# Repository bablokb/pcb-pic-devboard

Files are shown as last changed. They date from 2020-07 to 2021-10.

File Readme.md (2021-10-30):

Development board for PIC12/PIC16 microcontrollers
==================================================

This repository contains the design-files (Kicad) for three PIC12/PIC16
development boards.

PIC-Dev-Board
-------------

This is a full sized dev-board, see directory `pic-dev-board.kicad`:

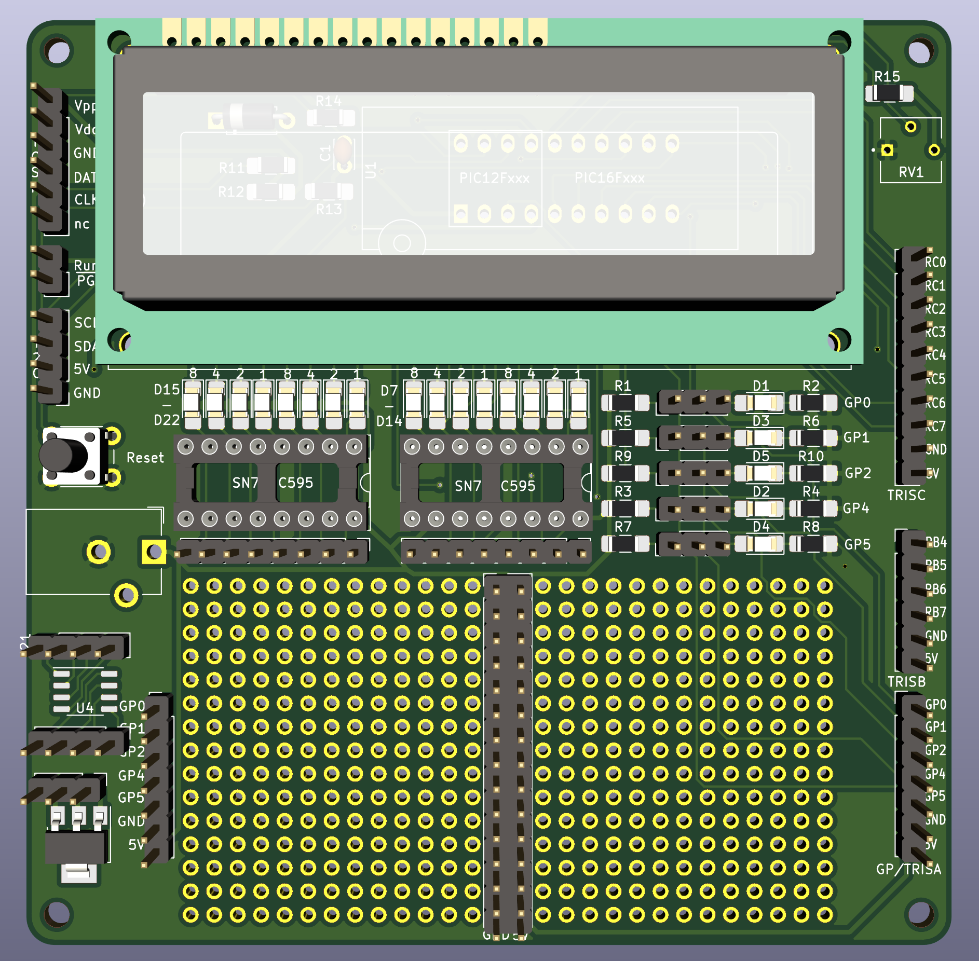
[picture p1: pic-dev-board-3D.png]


It supports:

  - a PIC12 or a 20-pin PIC16
  - configurable pullups or LEDs on GP0-GP5
  - two shift-registers with LEDs to output 8-16 bits using two GPs
    (see [project pic-sn74hc595](https://github.com/bablokb/pic-sn74hc595))
  - a LCD1602 attached to the first shift-register
    (see [project pic-hd44780_lcd](https://github.com/bablokb/pic-hd44780_lcd))
  - ICSP programming
  - all pins broken out to connectors (TRISB/TRISC only available for PIC16)
  - a large prototyping-area

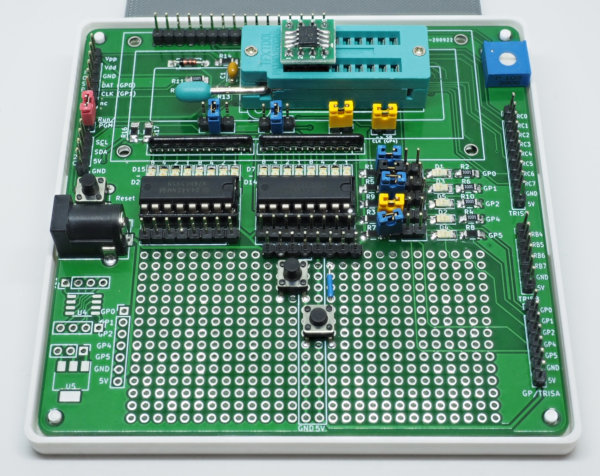
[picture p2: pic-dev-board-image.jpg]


PIC12-Dev-PCB
-------------

This is a small dev-board for PIC12 MCUs designed for plugging into a
breadboard, see directory `pic12-dev-pcb`:

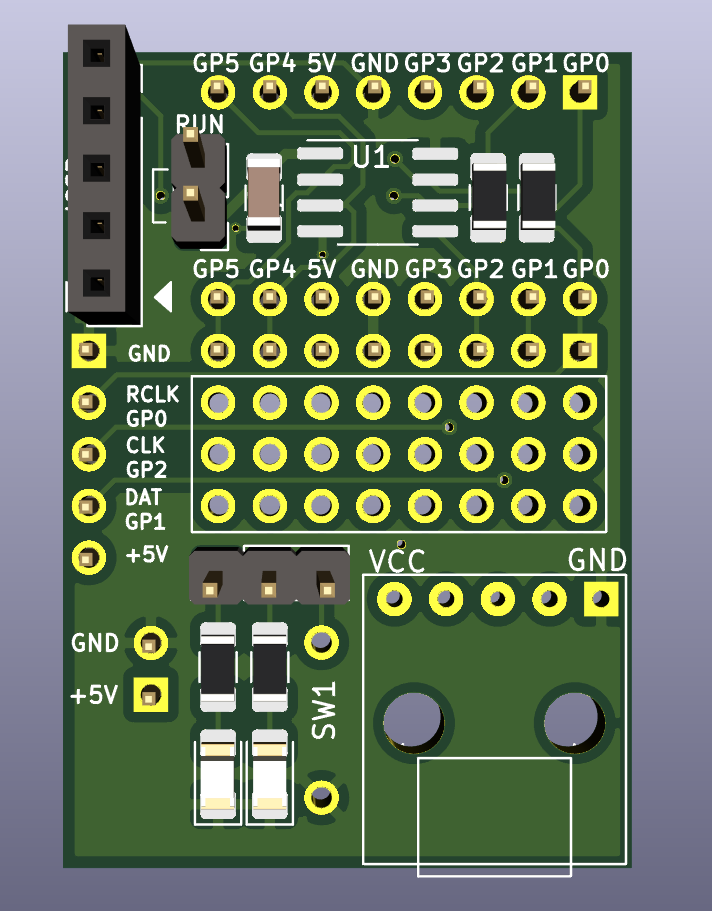
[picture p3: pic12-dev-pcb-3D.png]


It supports:

  - PIC12 in SO-8 package
  - ICSP programming
  - connector for an external SN74HC595-pcb
    (see [project pic-sn74hc595](https://github.com/bablokb/pic-sn74hc595)
  - also usable as I2C-connector
  - power-supply using a small micro-USB-connector breakout
  - connector for power-out (should align with the power-rails of the breadboard)
  - a small prototyping area
  - a small switch (optional)
  - two LEDs (optional)

Minimal Stripboard Version
--------------------------

In the directory `pic12-dev-stripboard.kicad` you find the schema and layout for
a minimal stripboard version:

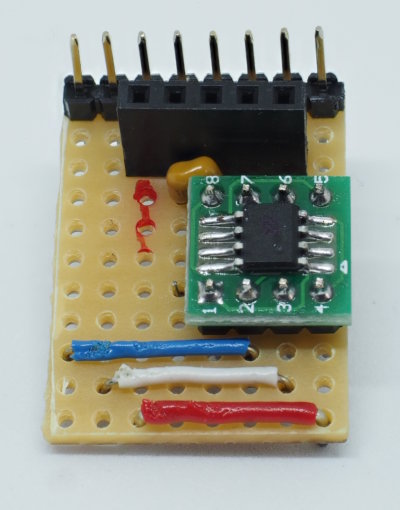
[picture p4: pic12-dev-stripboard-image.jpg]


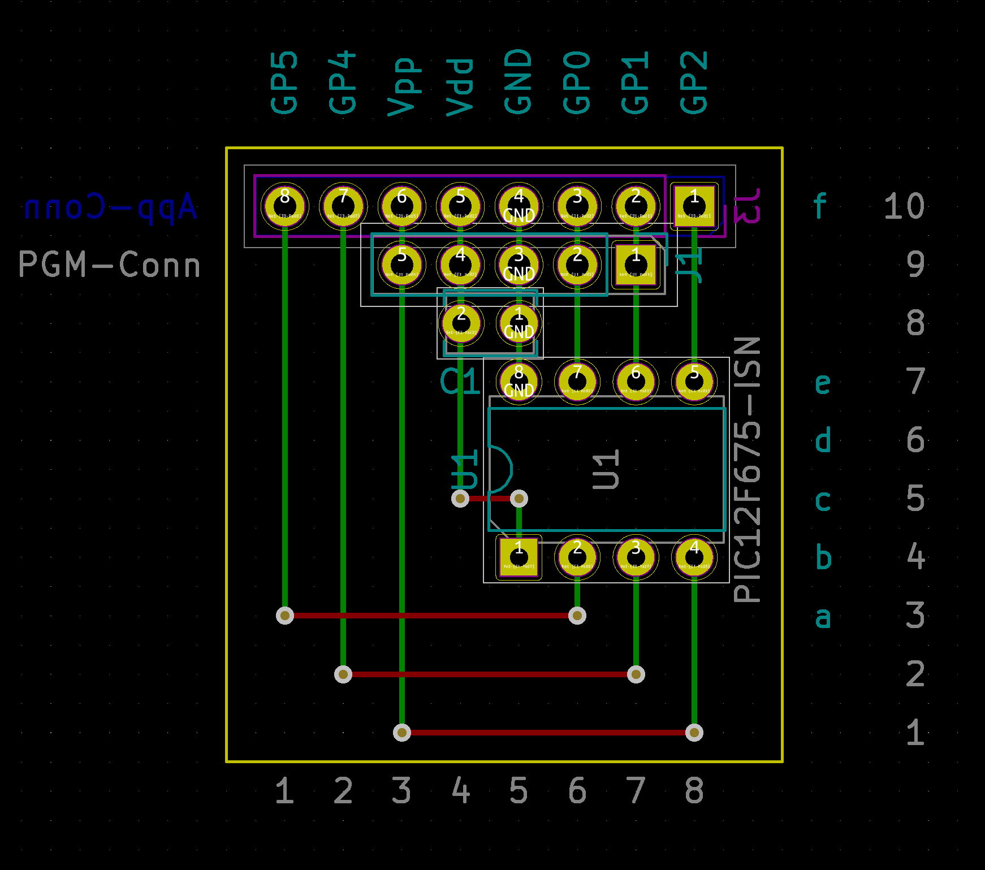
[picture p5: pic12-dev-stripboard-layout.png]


This is a simple solution for plugging a PIC12 into a breadboard.

This version is not meant for ICSP (in-circuit serial
programming), since it does not have any components to guard the rest of the
circuit during programming.

License
-------

Shield: [![CC BY-SA 4.0][cc-by-sa-shield]][cc-by-sa]

This work is licensed under a
[Creative Commons Attribution-ShareAlike 4.0 International
License][cc-by-sa].

[][cc-by-sa]

[cc-by-sa]: http://creativecommons.org/licenses/by-sa/4.0/
[cc-by-sa-image]: https://licensebuttons.net/l/by-sa/4.0/88x31.png
[cc-by-sa-shield]:
https://img.shields.io/badge/License-CC%20BY--SA%204.0-lightgrey.svg

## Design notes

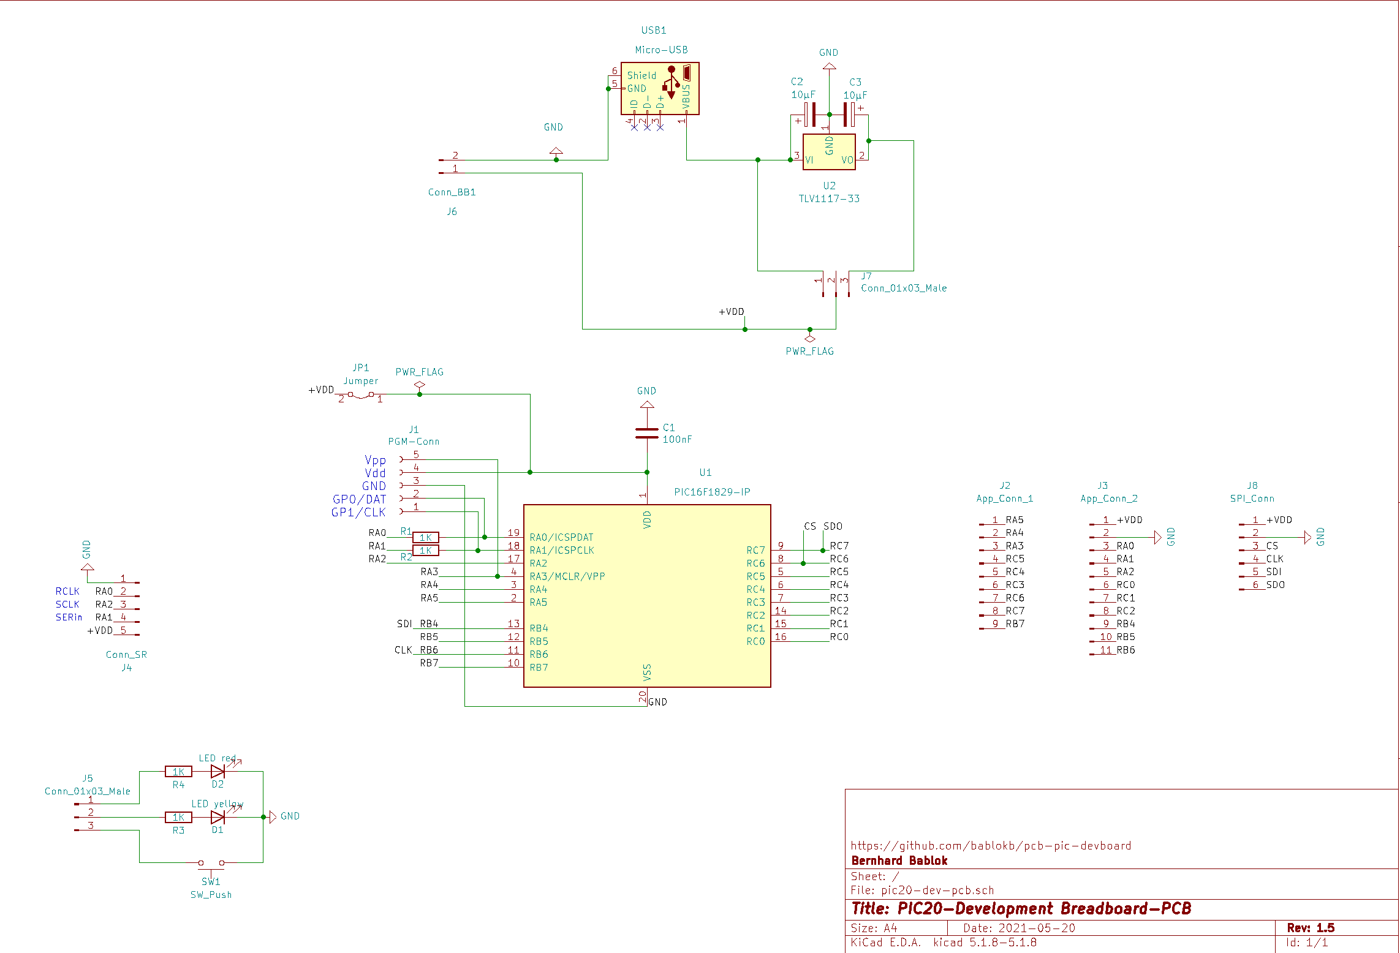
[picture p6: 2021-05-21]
pic20-dev-pcb-schematic.png

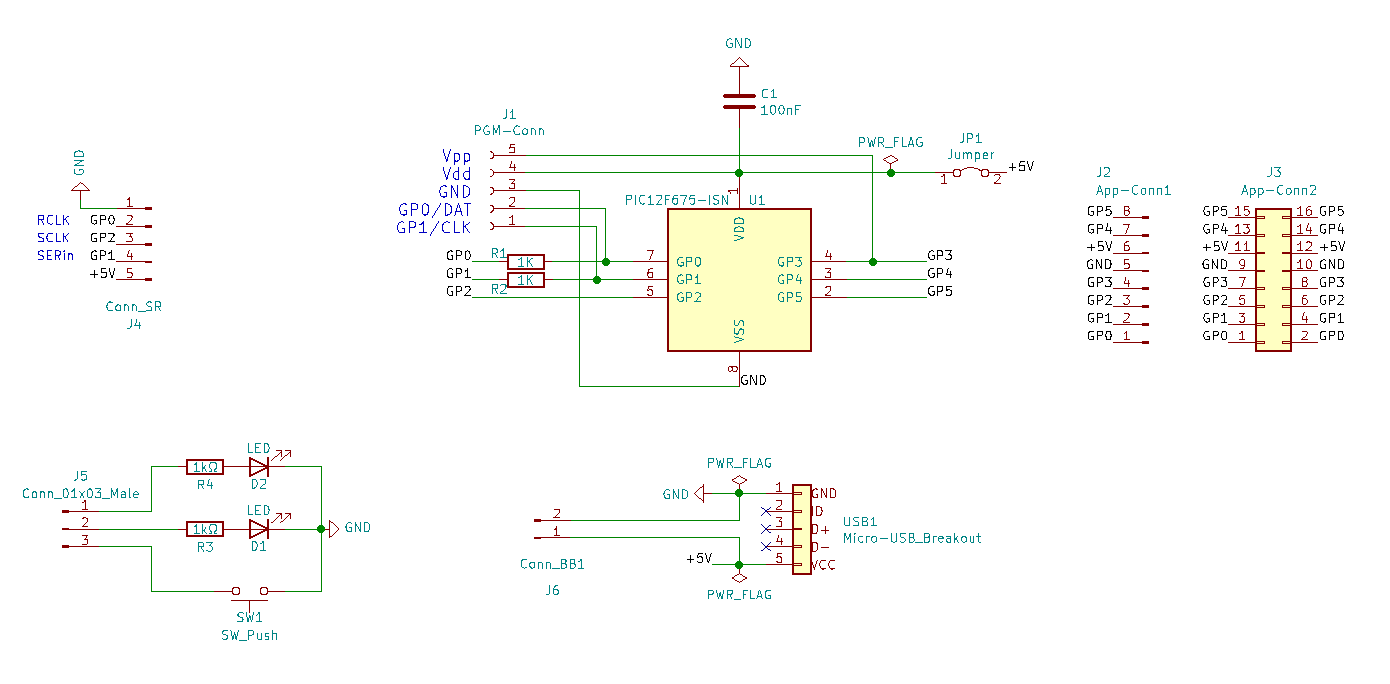
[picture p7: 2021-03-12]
pic12-dev-pcb-schematic.png

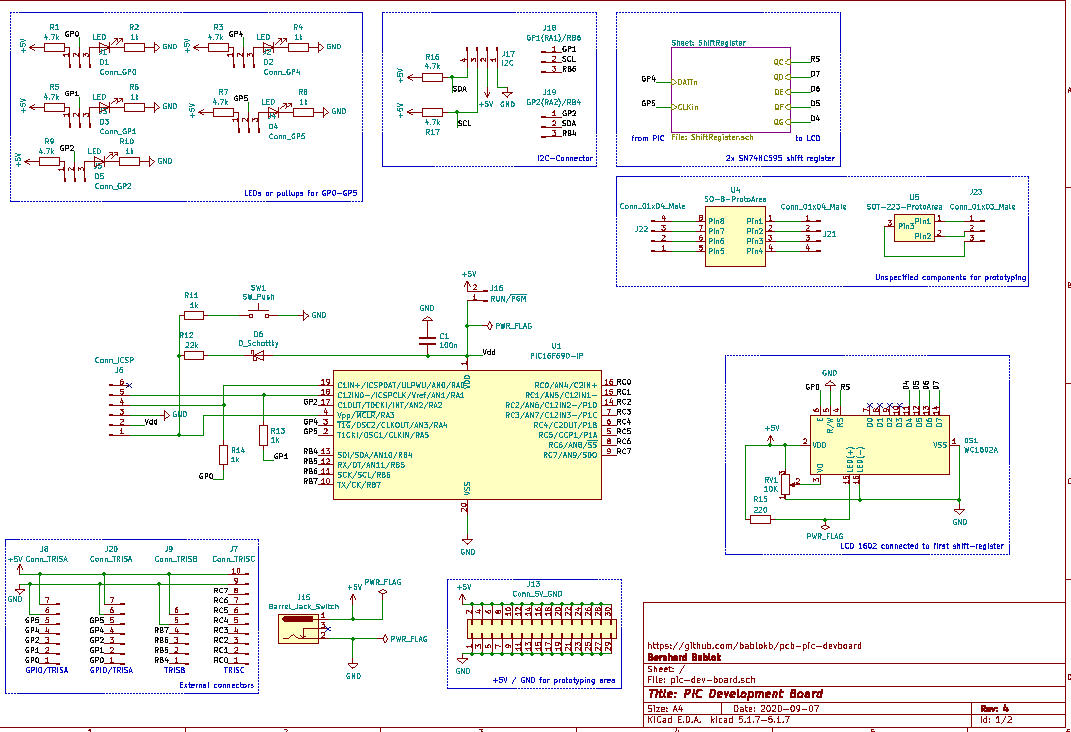
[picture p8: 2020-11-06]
pic-dev-board-schematic.png

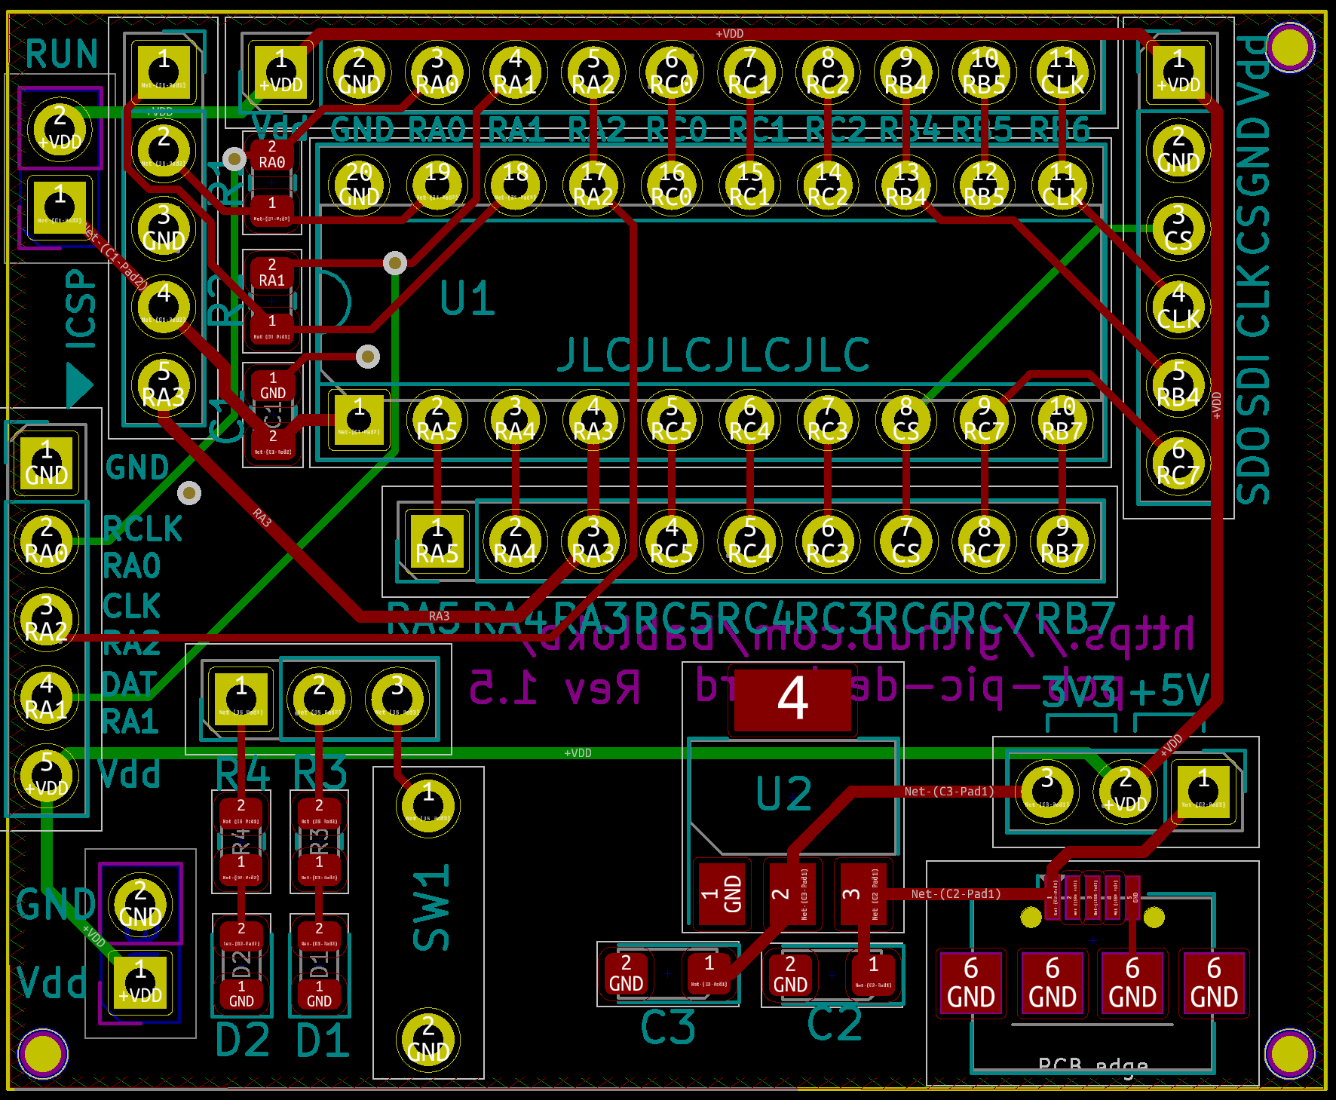
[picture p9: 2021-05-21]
pic20-dev-pcb-layout.png

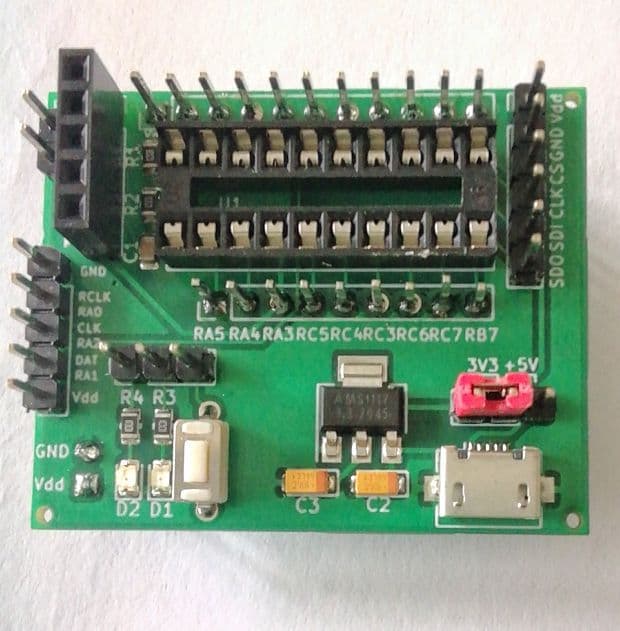
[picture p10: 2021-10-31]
pic20-dev-pcb.jpg

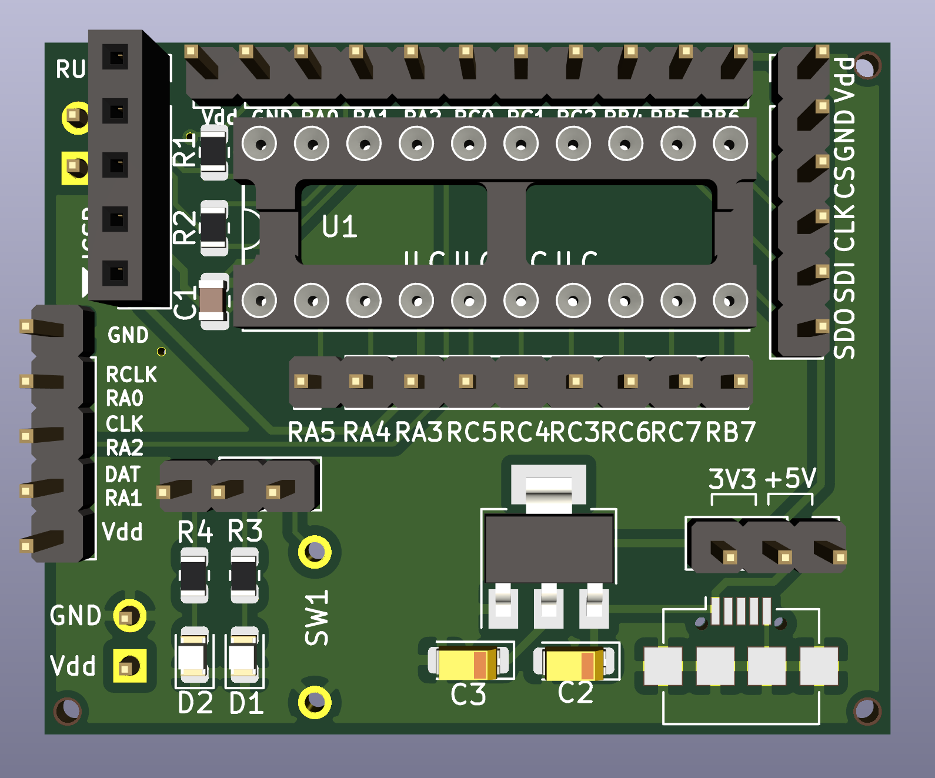
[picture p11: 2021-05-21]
pic20-dev-pcb-3D.png

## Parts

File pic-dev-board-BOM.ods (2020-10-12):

Ref | Qnty | Value | Note
C1 | 1 | 100n, THT 2,5mm | for PIC
D1-D5, D7-D14, D15-D22 | 21 | LED 1206 | for GP0-GP5 and shift-registers
D6 | 1 | BAT85 | PIC programming interface
DS1 | 1 | WC1602A | display, 1x16 female (optional)
J1-J5 | 5 | 1x03 | pullup/led for GP0-GP5 (shunts)
J6 | 1 | 1x06 | ICSP
J7 | 1 | 1x10 | TRISC
J8, J20 | 2 | 1x07 | GP/TRISA
J9 | 1 | 1x06 | TRISB
J10 | 1 | 1x02 | DATin for shift-register (shunt)
J11 | 1 | 1x08 | shift-register out (optional)
J12 | 1 | 1x08 | shift-register out (optional)
(J13) | 1 | 2x15 | GND/5V on prototyping-area (optional)
J14 | 1 | 1x02 | CLKin for shift-register (shunt)
J15 | 1 | Barrel-Jack | Power
J16 | 1 | 1x02 | RUN/PGM (shunt)
J17 | 1 | 1x04 | I2C
J18 | 1 | 1x03 | SCL select GP1/RB6 (shunt)
J19 | 1 | 1x03 | SDA select GP2/RB4 (shunt)
(J21, J22) | 2 | 1x04 | SO-8 breakout (optional)
(J23) | 1 | 1x03 | SOT-223 breakout (optional)
R1, R3, R5, R7, R9 | 5 | SMD 1206 4.7k | pullups for GP0-GP5
R16, R17 | 2 | SMD 1206 4.7k | pullups for I2C
R2, R4, R6, R8, R10 | 5 | SMD 1206 1k | for LEDs on GP0-GP5
R11, R13, R14 | 3 | SMD 1206 1k | PIC programming interface
R12 | 1 | SMD 1206 22k | PIC programming interface
R15 | 1 | SMD 1206 220 | for display (optional)
RN1, RN2 | 2 | R-Net 680 | for shift-register LEDs
RV1 | 1 | TRIM 3362P 10K | for display (optional)
SW1 | 1 | SW_Push | reset
U1 | 1 | test-socket | or normal socket together with display
U2, U3 | 2 | 74HC595 | shift-registers (or 2x8 sockets)
(U4) | 1 | SO-8 | optional
(U5) | 1 | SOT-223 | optional

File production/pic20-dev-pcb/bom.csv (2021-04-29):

Comment | Designator | Footprint | LCSC
100nF | C1 | Capacitor_SMD:C_0805_2012Metric | C49678
10µF | C2,C3 | Capacitor_Tantalum_SMD:CP_EIA-3216-18_Kemet-A | C7171
LED yellow | D1 | LED_SMD:LED_0805_2012Metric | C2296
LED red | D2 | LED_SMD:LED_0805_2012Metric | C84256
PGM-Conn | J1 | Connector_PinSocket_2.54mm:PinSocket_1x05_P2.54mm_Vertical
App_Conn_1 | J2 | Connector_PinHeader_2.54mm:PinHeader_1x09_P2.54mm_Vertical
App_Conn_2 | J3 | Connector_PinHeader_2.54mm:PinHeader_1x11_P2.54mm_Vertical
Conn_SR | J4 | Connector_PinHeader_2.54mm:PinHeader_1x05_P2.54mm_Vertical
Conn_01x03_Male | J5,J7 | Connector_PinHeader_2.54mm:PinHeader_1x03_P2.54mm_Vertical
Conn_BB1 | J6 | Connector_PinHeader_2.54mm:PinHeader_1x02_P2.54mm_Vertical
SPI_Conn | J8 | Connector_PinHeader_2.54mm:PinHeader_1x06_P2.54mm_Vertical
Jumper | JP1 | Connector_PinHeader_2.54mm:PinHeader_1x02_P2.54mm_Vertical
1K | R1,R2,R3,R4 | Resistor_SMD:R_0805_2012Metric | C17513
SW_Push | SW1 | user:SW_PUSH_SLIM_1x4
PIC16F1829-IP | U1 | Package_DIP:DIP-20_W7.62mm_Socket
AMS1117-33 | U2 | Package_TO_SOT_SMD:SOT-223 | C6186
Micro-USB | USB1 | user:USB_Micro-B_JLCPCB_40942 | C40942

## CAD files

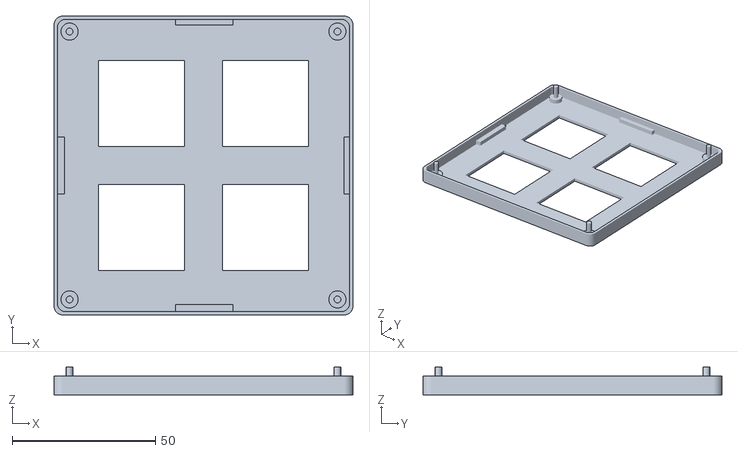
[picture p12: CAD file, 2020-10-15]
pic-dev-board-base.stl
104.3 x 104.3 x 9.60

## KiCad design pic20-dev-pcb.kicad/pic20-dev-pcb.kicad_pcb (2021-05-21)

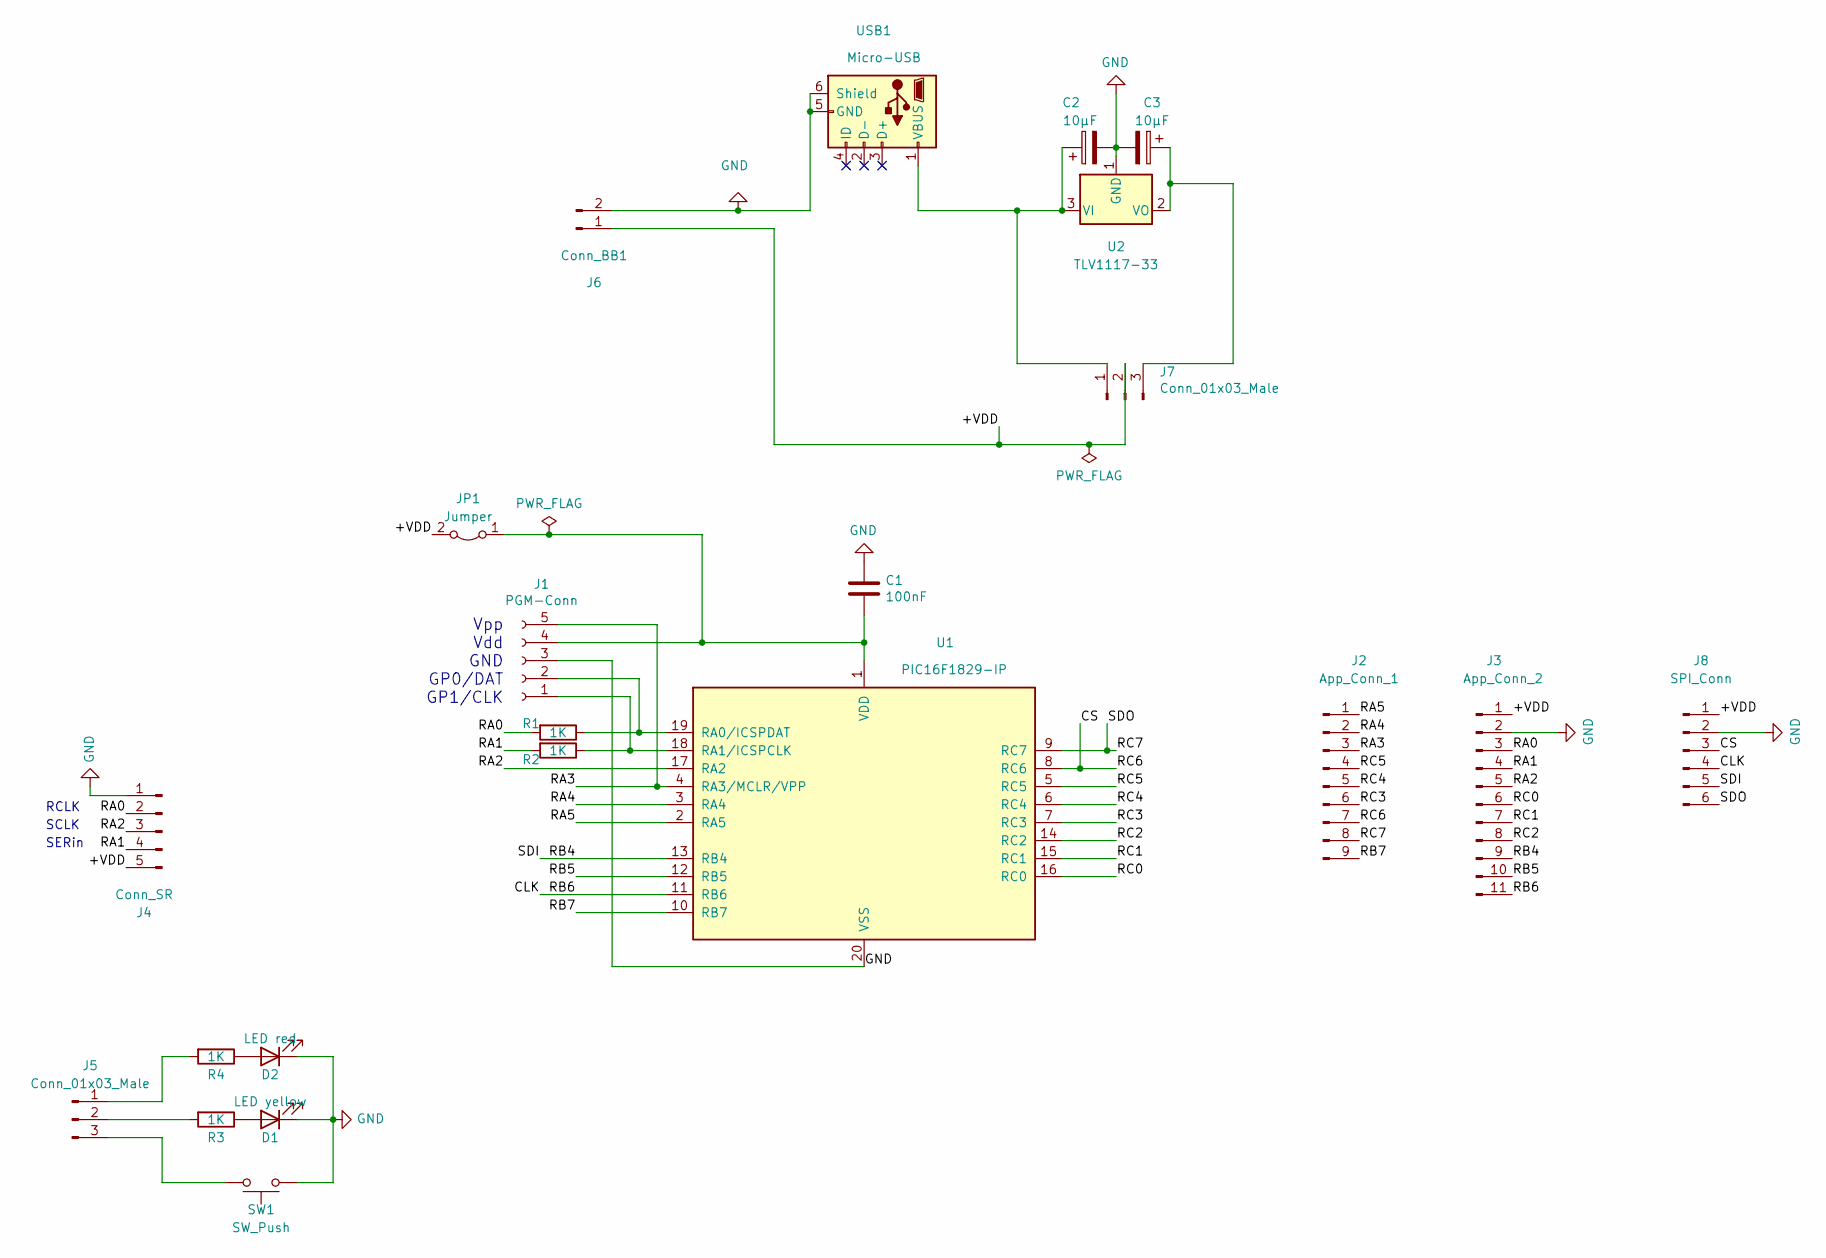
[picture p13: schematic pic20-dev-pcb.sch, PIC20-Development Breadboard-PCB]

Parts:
C1: 100nF; C_0805_2012Metric; LCSC C49678
C2, C3: 10µF; CP_EIA-3216-18_Kemet-A; LCSC C7171
D1: LED yellow; LED_0805_2012Metric; LCSC C2296
D2: LED red; LED_0805_2012Metric; LCSC C84256
J1: PGM-Conn; PinSocket_1x05_P2.54mm_Vertical
J2: App_Conn_1; PinHeader_1x09_P2.54mm_Vertical
J3: App_Conn_2; PinHeader_1x11_P2.54mm_Vertical
J4: Conn_SR; PinHeader_1x05_P2.54mm_Vertical
J5, J7: Conn_01x03_Male; PinHeader_1x03_P2.54mm_Vertical
J6: Conn_BB1; PinHeader_1x02_P2.54mm_Vertical
J8: SPI_Conn; PinHeader_1x06_P2.54mm_Vertical
JP1: Jumper; PinHeader_1x02_P2.54mm_Vertical
R1, R2, R3, R4: 1K; R_0805_2012Metric; LCSC C17513
SW1: SW_Push; SW_PUSH_SLIM_1x4
U1: PIC16F1829-IP; DIP-20_W7.62mm_Socket
U2: TLV1117-33; SOT-223; LCSC C6186
USB1: Micro-USB; USB_Micro-B_JLCPCB_40942; LCSC C40942

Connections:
/+VDD: J3.1, J4.5, J6.1, J7.2, J8.1, JP1.2 (B)
/CLK: J3.11, J8.4, U1.11 (RB6)
/CS: J2.7, J8.3, U1.8 (RC6)
/RA0: J3.3, J4.2, R1.2
/RA1: J3.4, J4.4, R2.2
/RA2: J3.5, J4.3, U1.17 (RA2)
/RA3: J1.5, J2.3, U1.4 (RA3/MCLR/VPP)
/RA4: J2.2, U1.3 (RA4)
/RA5: J2.1, U1.2 (RA5)
/RB4: J3.9, J8.5, U1.13 (RB4)
/RB5: J3.10, U1.12 (RB5)
/RB7: J2.9, U1.10 (RB7)
/RC0: J3.6, U1.16 (RC0)
/RC1: J3.7, U1.15 (RC1)
/RC2: J3.8, U1.14 (RC2)
/RC3: J2.6, U1.7 (RC3)
/RC4: J2.5, U1.6 (RC4)
/RC5: J2.4, U1.5 (RC5)
/RC7: J2.8, J8.6, U1.9 (RC7)
GND: C1.1, C2.2, C3.2, D1.1 (K), D2.1 (K), J1.3, J3.2, J4.1, J6.2, J8.2, SW1.2, U1.20 (VSS), U2.1 (GND), USB1.5 (GND), USB1.6 (Shield)
unnamed: C1.2, J1.4, JP1.1 (A), U1.1 (VDD)
unnamed: C2.1, J7.1, U2.3 (VI), USB1.1 (VBUS)
unnamed: C3.1, J7.3, U2.2 (VO)
unnamed: D1.2 (A), R3.1
unnamed: D2.2 (A), R4.1
unnamed: J1.1, R2.1, U1.18 (RA1/ICSPCLK)
unnamed: J1.2, R1.1, U1.19 (RA0/ICSPDAT)
unnamed: J5.1, R4.2
unnamed: J5.2, R3.2
unnamed: J5.3, SW1.1

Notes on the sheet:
Vpp Vdd GND GP0/DAT GP1/CLK
SERin
RCLK
SCLK

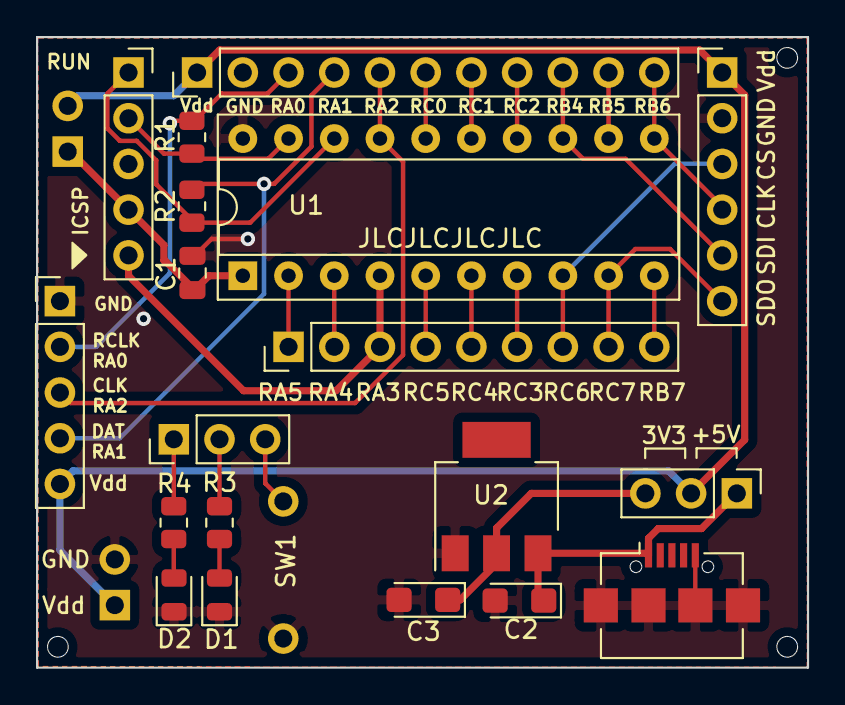
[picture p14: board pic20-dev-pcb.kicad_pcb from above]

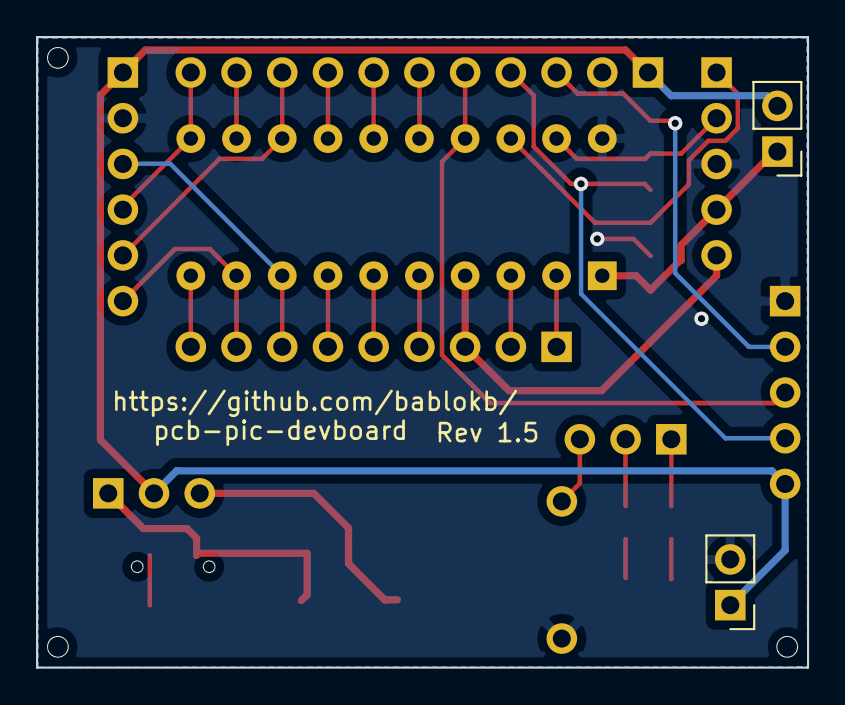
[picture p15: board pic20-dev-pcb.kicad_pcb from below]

Board: 2 copper layers, 42.8 x 35.0 mm, 22 parts (2 on the bottom side), 30 nets.

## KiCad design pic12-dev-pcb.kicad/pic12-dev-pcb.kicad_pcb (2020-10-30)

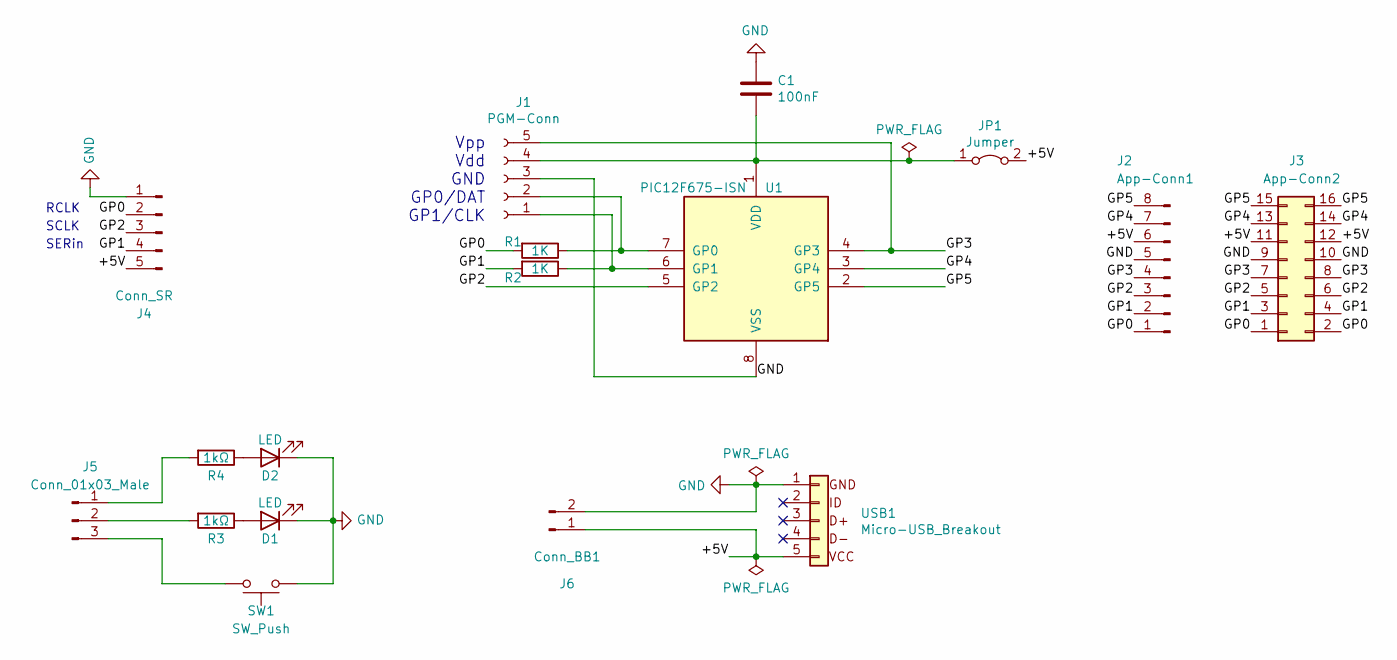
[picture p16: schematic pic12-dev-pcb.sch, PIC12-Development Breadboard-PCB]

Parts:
C1: 100nF; C_1206_3216Metric_Pad1.42x1.75mm_HandSolder
D1, D2: LED; LED_1206_3216Metric_Pad1.42x1.75mm_HandSolder
J1: PGM-Conn; PinSocket_1x05_P2.54mm_Vertical
J2: App-Conn1; PinHeader_1x08_P2.54mm_Vertical
J3: App-Conn2; PinHeader_2x08_P2.54mm_Vertical
J4: Conn_SR; PinHeader_1x05_P2.54mm_Vertical
J5: Conn_01x03_Male; PinHeader_1x03_P2.54mm_Vertical
J6: Conn_BB1; PinHeader_1x02_P2.54mm_Vertical
JP1: Jumper; PinHeader_1x02_P2.54mm_Vertical
R1, R2: 1K; R_1206_3216Metric_Pad1.42x1.75mm_HandSolder
R3, R4: 1kΩ; R_1206_3216Metric_Pad1.30x1.75mm_HandSolder
SW1: SW_Push; SW_PUSH_SLIM_1x4
U1: PIC12F675-ISN; SO-8_3.9x4.9mm_P1.27mm_HandSolder
USB1: Micro-USB_Breakout

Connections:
/+5V: J2.6, J3.11, J3.12, J4.5, J6.1, JP1.2 (B), USB1.5
/GP0: J2.1, J3.1, J3.2, J4.2, R1.2
/GP1: J2.2, J3.3, J3.4, J4.4, R2.2
/GP2: J2.3, J3.5, J3.6, J4.3, U1.5 (GP2)
/GP3: J1.5, J2.4, J3.7, J3.8, U1.4 (GP3)
/GP4: J2.7, J3.13, J3.14, U1.3 (GP4)
/GP5: J2.8, J3.15, J3.16, U1.2 (GP5)
GND: C1.1, D1.1 (K), D2.1 (K), J1.3, J2.5, J3.9, J3.10, J4.1, J6.2, SW1.2, U1.8 (VSS), USB1.1
unnamed: C1.2, J1.4, JP1.1 (A), U1.1 (VDD)
unnamed: D1.2 (A), R3.1
unnamed: D2.2 (A), R4.1
unnamed: J1.1, R2.1, U1.6 (GP1)
unnamed: J1.2, R1.1, U1.7 (GP0)
unnamed: J5.1, R4.2
unnamed: J5.2, R3.2
unnamed: J5.3, SW1.1

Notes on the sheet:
Vpp Vdd GND GP0/DAT GP1/CLK
SERin
RCLK
SCLK

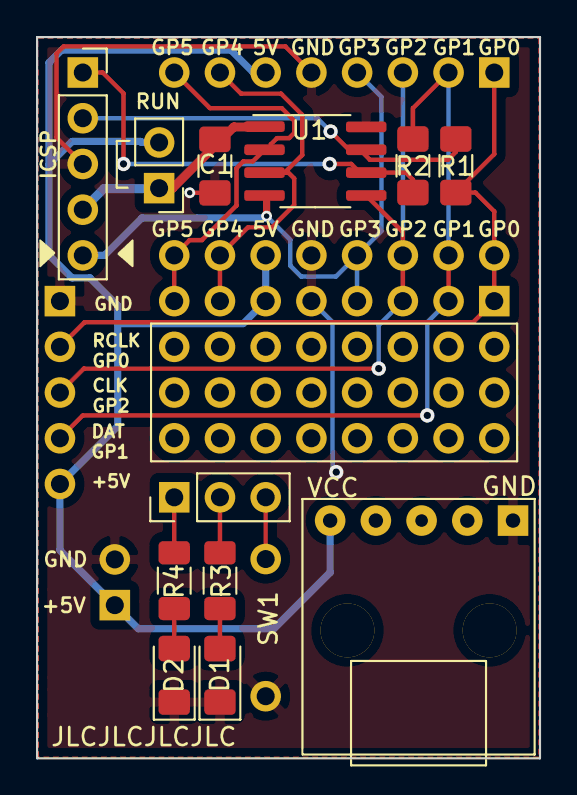
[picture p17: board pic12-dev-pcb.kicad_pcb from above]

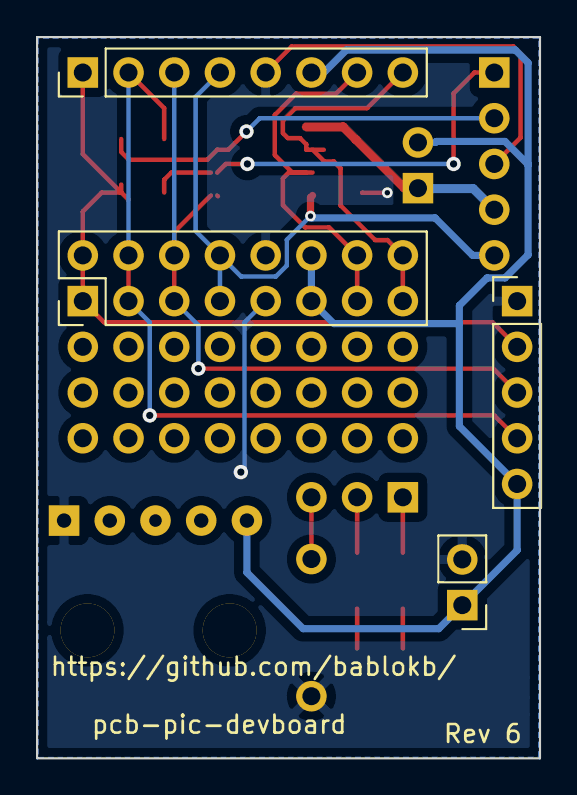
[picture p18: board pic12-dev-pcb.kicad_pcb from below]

Board: 2 copper layers, 27.9 x 40.1 mm, 17 parts (4 on the bottom side), 16 nets.

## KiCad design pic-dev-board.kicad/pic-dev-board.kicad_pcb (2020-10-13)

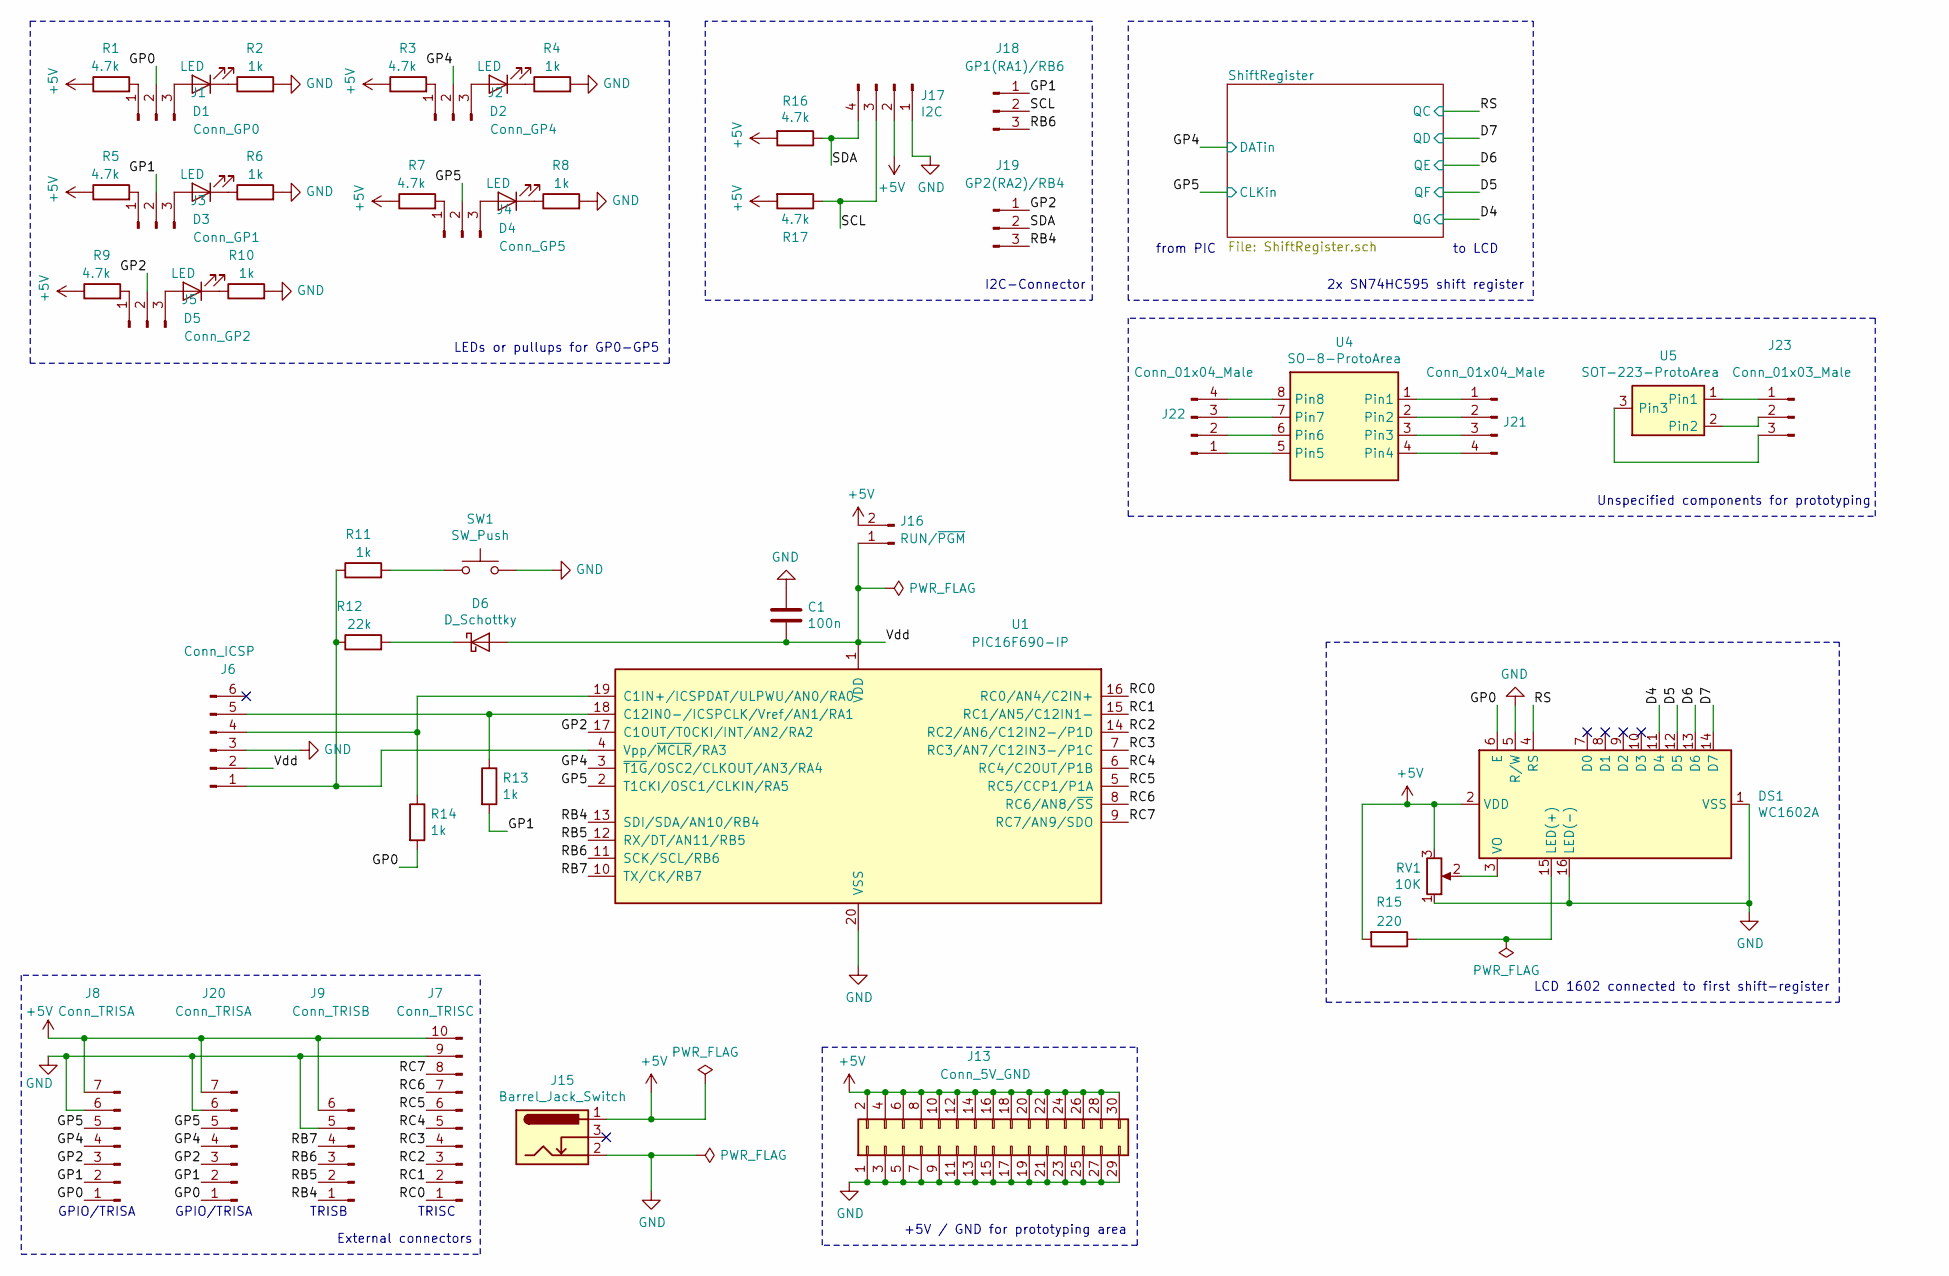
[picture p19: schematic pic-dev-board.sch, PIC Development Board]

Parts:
C1: 100n; C_Disc_D3.0mm_W2.0mm_P2.50mm
D1, D2, D3, D4, D5: LED; LED_1206_3216_Pad1.7x1.75mm_BB
D6: D_Schottky; D_A-405_P7.62mm_Horizontal
DS1: WC1602A; WC1602A_Connector
J1: Conn_GP0; PinHeader_1x03_P2.54mm_Vertical
J2: Conn_GP4; PinHeader_1x03_P2.54mm_Vertical
J3: Conn_GP1; PinHeader_1x03_P2.54mm_Vertical
J4: Conn_GP5; PinHeader_1x03_P2.54mm_Vertical
J5: Conn_GP2; PinHeader_1x03_P2.54mm_Vertical
J6: Conn_ICSP; PinHeader_1x06_P2.54mm_Vertical
J7: Conn_TRISC; PinHeader_1x10_P2.54mm_Vertical
J8, J20: Conn_TRISA; PinHeader_1x07_P2.54mm_Vertical
J9: Conn_TRISB; PinHeader_1x06_P2.54mm_Vertical
J13: Conn_5V_GND; PinHeader_2x15_P2.54mm_Vertical_Slim
J15: Barrel_Jack_Switch; BarrelJack_CUI_PJ-102AH_Horizontal
J16: RUN/~PGM; PinHeader_1x02_P2.54mm_Vertical
J17: I2C; PinHeader_1x04_P2.54mm_Vertical
J18: GP1(RA1)/RB6; PinHeader_1x03_P2.54mm_Vertical
J19: GP2(RA2)/RB4; PinHeader_1x03_P2.54mm_Vertical
J21, J22: Conn_01x04_Male; PinHeader_1x04_P2.54mm_Vertical
J23: Conn_01x03_Male; PinHeader_1x03_P2.54mm_Vertical
R1, R3, R5, R7, R9, R16, R17: 4.7k; R_1206_3216_Pad1.7x1.75mm_BB
R2, R4, R6, R8, R10, R11, R13, R14: 1k; R_1206_3216_Pad1.7x1.75mm_BB
R12: 22k; R_1206_3216_Pad1.7x1.75mm_BB
R15: 220; R_1206_3216_Pad1.7x1.75mm_BB
RV1: 10K; TRIM_3362P-1-103
SW1: SW_Push; SW_PUSH_6mm_H9.5mm
U1: PIC16F690-IP; DIP_Socket-20_W4.3_W5.08_W7.62_W10.16_W10.9_3M_220-3342-00-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
U4: SO-8-ProtoArea; SO-8_3.9x4.9mm_P1.27mm
U5: SOT-223-ProtoArea; SOT-223

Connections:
+5V: DS1.2 (VDD), J7.10, J8.7, J9.6, J13.2, J13.4, J13.6, J13.8, J13.10, J13.12, J13.14, J13.16, J13.18, J13.20, J13.22, J13.24, J13.26, J13.28, J13.30, J15.1, J16.2, J17.2, J20.7, R1.1, R3.1, R5.1, R7.1, R9.1, R15.2, R16.2, R17.2, RV1.3; also elsewhere on the board
/D4: DS1.11 (D4); also elsewhere on the board
/D5: DS1.12 (D5); also elsewhere on the board
/D6: DS1.13 (D6); also elsewhere on the board
/D7: DS1.14 (D7); also elsewhere on the board
/GP0: DS1.6 (E), J1.2, J8.1, J20.1, R14.2
/GP1: J3.2, J8.2, J18.1, J20.2, R13.2
/GP2: J5.2, J8.3, J19.1, J20.3, U1.17 (C1OUT/T0CKI/INT/AN2/RA2)
/GP4: J2.2, J8.4, J20.4, U1.3 (~T1G~/OSC2/CLKOUT/AN3/RA4); also elsewhere on the board
/GP5: J4.2, J8.5, J20.5, U1.2 (T1CKI/OSC1/CLKIN/RA5); also elsewhere on the board
/RB4: J9.1, J19.3, U1.13 (SDI/SDA/AN10/RB4)
/RB5: J9.2, U1.12 (RX/DT/AN11/RB5)
/RB6: J9.3, J18.3, U1.11 (SCK/SCL/RB6)
/RB7: J9.4, U1.10 (TX/CK/RB7)
/RC0: J7.1, U1.16 (RC0/AN4/C2IN+)
/RC1: J7.2, U1.15 (RC1/AN5/C12IN1-)
/RC2: J7.3, U1.14 (RC2/AN6/C12IN2-/P1D)
/RC3: J7.4, U1.7 (RC3/AN7/C12IN3-/P1C)
/RC4: J7.5, U1.6 (RC4/C2OUT/P1B)
/RC5: J7.6, U1.5 (RC5/CCP1/P1A)
/RC6: J7.7, U1.8 (RC6/AN8/~SS~)
/RC7: J7.8, U1.9 (RC7/AN9/SDO)
/RS: DS1.4 (RS); also elsewhere on the board
/SCL: J17.3, J18.2, R17.1
/SDA: J17.4, J19.2, R16.1
/Vdd: C1.2, D6.2 (A), J6.2, J16.1, U1.1 (VDD)
GND: C1.1, DS1.1 (VSS), DS1.5 (R/W), DS1.16 (LED(-)), J6.3, J7.9, J8.6, J9.5, J13.1, J13.3, J13.5, J13.7, J13.9, J13.11, J13.13, J13.15, J13.17, J13.19, J13.21, J13.23, J13.25, J13.27, J13.29, J15.2, J17.1, J20.6, R2.2, R4.2, R6.2, R8.2, R10.2, RV1.1, SW1.2, U1.20 (VSS); also elsewhere on the board
unnamed: D1.1 (K), R2.1
unnamed: D1.2 (A), J1.3
unnamed: D2.1 (K), R4.1
unnamed: D2.2 (A), J2.3
unnamed: D3.1 (K), R6.1
unnamed: D3.2 (A), J3.3
unnamed: D4.1 (K), R8.1
unnamed: D4.2 (A), J4.3
unnamed: D5.1 (K), R10.1
unnamed: D5.2 (A), J5.3
unnamed: D6.1 (K), R12.2
unnamed: DS1.3 (VO), RV1.2
unnamed: DS1.15 (LED(+)), R15.1
unnamed: J1.1, R1.2
unnamed: J2.1, R3.2
unnamed: J3.1, R5.2
unnamed: J4.1, R7.2
unnamed: J5.1, R9.2
unnamed: J6.1, R11.1, R12.1, U1.4 (Vpp/~MCLR~/RA3)
unnamed: J6.4, R14.1, U1.19 (C1IN+/ICSPDAT/ULPWU/AN0/RA0)
unnamed: J6.5, R13.1, U1.18 (C12IN0-/ICSPCLK/Vref/AN1/RA1)
unnamed: J21.1, U4.1 (Pin1)
unnamed: J21.2, U4.2 (Pin2)
unnamed: J21.3, U4.3 (Pin3)
unnamed: J21.4, U4.4 (Pin4)
unnamed: J22.1, U4.5 (Pin5)
unnamed: J22.2, U4.6 (Pin6)
unnamed: J22.3, U4.7 (Pin7)
unnamed: J22.4, U4.8 (Pin8)
unnamed: J23.1, U5.1 (Pin1)
unnamed: J23.2, U5.2 (Pin2)
unnamed: J23.3, U5.3 (Pin3)
unnamed: R11.2, SW1.1

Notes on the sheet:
GPIO/TRISA
TRISB
TRISC
I2C-Connector
LEDs or pullups for GP0-GP5
External connectors
LCD 1602 connected to first shift-register
from PIC
to LCD
+5V / GND for prototyping area
2x SN74HC595 shift register
Unspecified components for prototyping

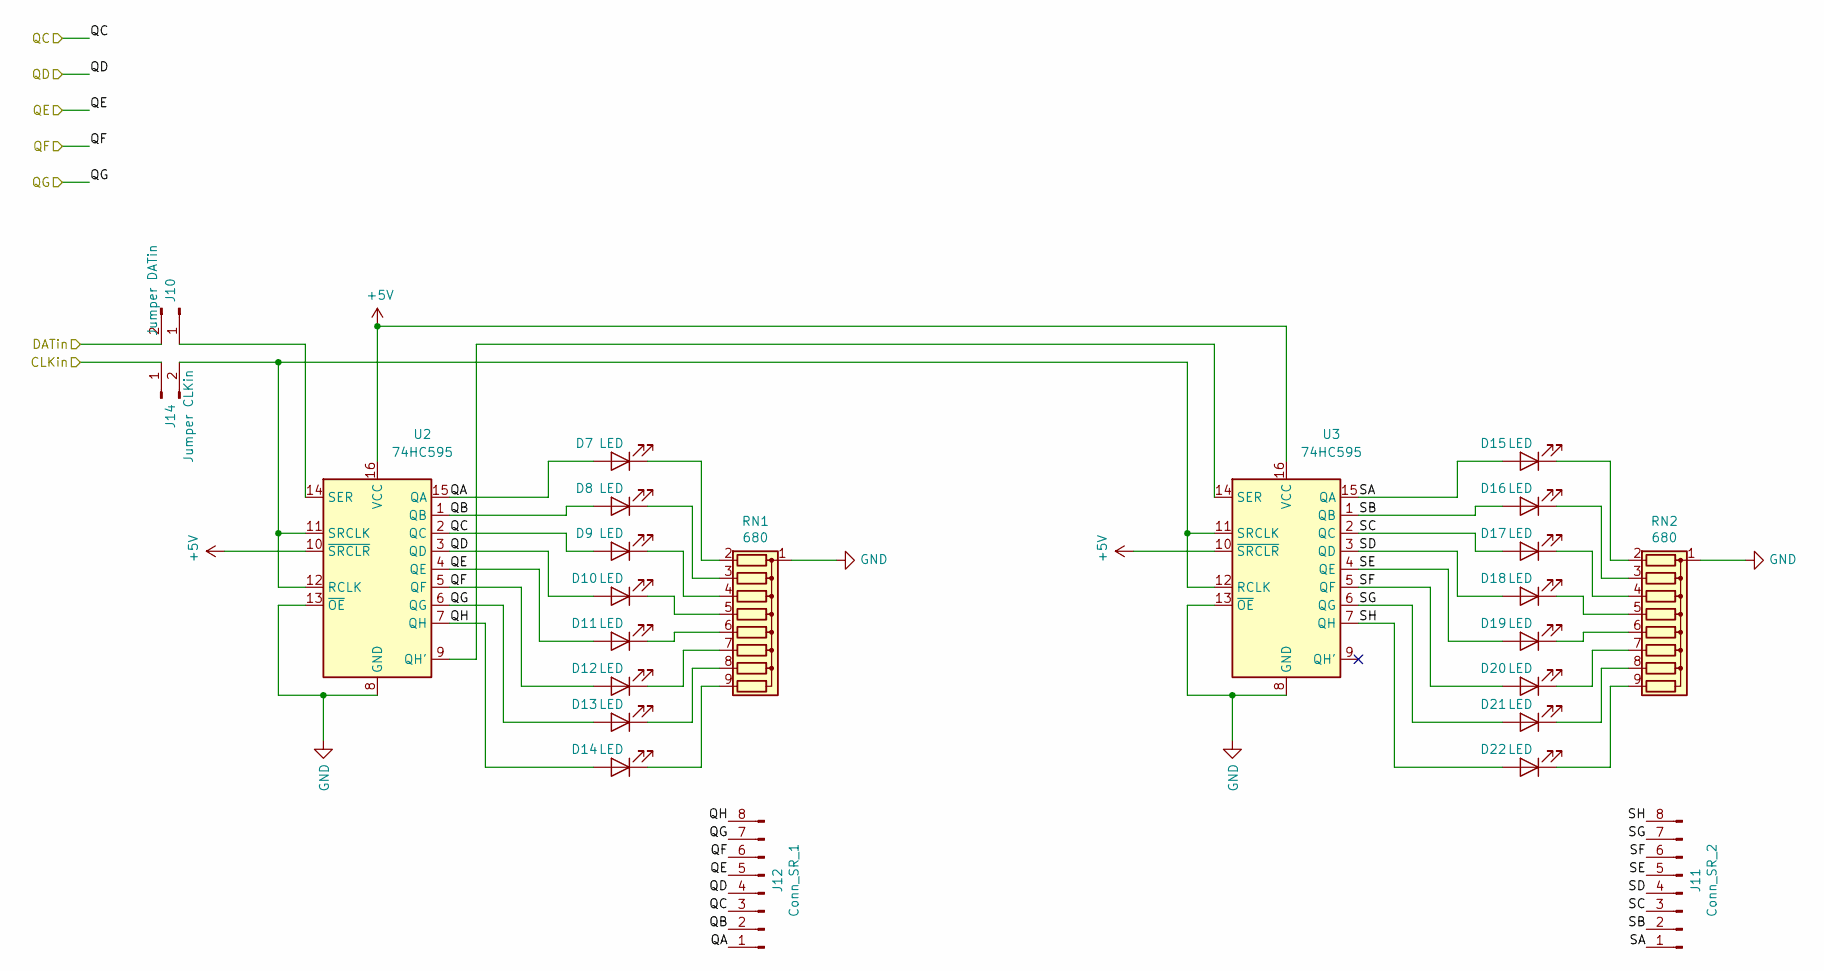
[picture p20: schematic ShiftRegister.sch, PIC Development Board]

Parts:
D7, D8, D9, D10, D11, D12, D13, D14, D15, D16, D17, D18, D19, D20, D21, D22: LED; LED_1206_3216_Pad1.7x1.75mm_BB
J10: Jumper DATin; PinHeader_1x02_P2.54mm_Vertical
J11: Conn_SR_2; PinHeader_1x08_P2.54mm_Vertical
J12: Conn_SR_1; PinHeader_1x08_P2.54mm_Vertical
J14: Jumper CLKin; PinHeader_1x02_P2.54mm_Vertical
RN1, RN2: 680; R_Array_SIP9
U2, U3: 74HC595; DIP-16_W7.62mm_Socket

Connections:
+5V: U2.10 (~SRCLR), U2.16 (VCC), U3.10 (~SRCLR), U3.16 (VCC); also elsewhere on the board
/D4: D13.2 (A), J12.7, U2.6 (QG); also elsewhere on the board
/D5: D12.2 (A), J12.6, U2.5 (QF); also elsewhere on the board
/D6: D11.2 (A), J12.5, U2.4 (QE); also elsewhere on the board
/D7: D10.2 (A), J12.4, U2.3 (QD); also elsewhere on the board
/GP4: J10.2; also elsewhere on the board
/GP5: J14.1; also elsewhere on the board
/RS: D9.2 (A), J12.3, U2.2 (QC); also elsewhere on the board
/ShiftRegister/QA: D7.2 (A), J12.1, U2.15 (QA)
/ShiftRegister/QB: D8.2 (A), J12.2, U2.1 (QB)
/ShiftRegister/QH: D14.2 (A), J12.8, U2.7 (QH)
/ShiftRegister/SA: D15.2 (A), J11.1, U3.15 (QA)
/ShiftRegister/SB: D16.2 (A), J11.2, U3.1 (QB)
/ShiftRegister/SC: D17.2 (A), J11.3, U3.2 (QC)
/ShiftRegister/SD: D18.2 (A), J11.4, U3.3 (QD)
/ShiftRegister/SE: D19.2 (A), J11.5, U3.4 (QE)
/ShiftRegister/SF: D20.2 (A), J11.6, U3.5 (QF)
/ShiftRegister/SG: D21.2 (A), J11.7, U3.6 (QG)
/ShiftRegister/SH: D22.2 (A), J11.8, U3.7 (QH)
GND: RN1.1 (common), RN2.1 (common), U2.8 (GND), U2.13 (~OE), U3.8 (GND), U3.13 (~OE); also elsewhere on the board
unnamed: D7.1 (K), RN1.2 (R1)
unnamed: D8.1 (K), RN1.3 (R2)
unnamed: D9.1 (K), RN1.4 (R3)
unnamed: D10.1 (K), RN1.5 (R4)
unnamed: D11.1 (K), RN1.6 (R5)
unnamed: D12.1 (K), RN1.7 (R6)
unnamed: D13.1 (K), RN1.8 (R7)
unnamed: D14.1 (K), RN1.9 (R8)
unnamed: D15.1 (K), RN2.2 (R1)
unnamed: D16.1 (K), RN2.3 (R2)
unnamed: D17.1 (K), RN2.4 (R3)
unnamed: D18.1 (K), RN2.5 (R4)
unnamed: D19.1 (K), RN2.6 (R5)
unnamed: D20.1 (K), RN2.7 (R6)
unnamed: D21.1 (K), RN2.8 (R7)
unnamed: D22.1 (K), RN2.9 (R8)
unnamed: J10.1, U2.14 (SER)
unnamed: J14.2, U2.11 (SRCLK), U2.12 (RCLK), U3.11 (SRCLK), U3.12 (RCLK)
unnamed: U2.9 (QH'), U3.14 (SER)

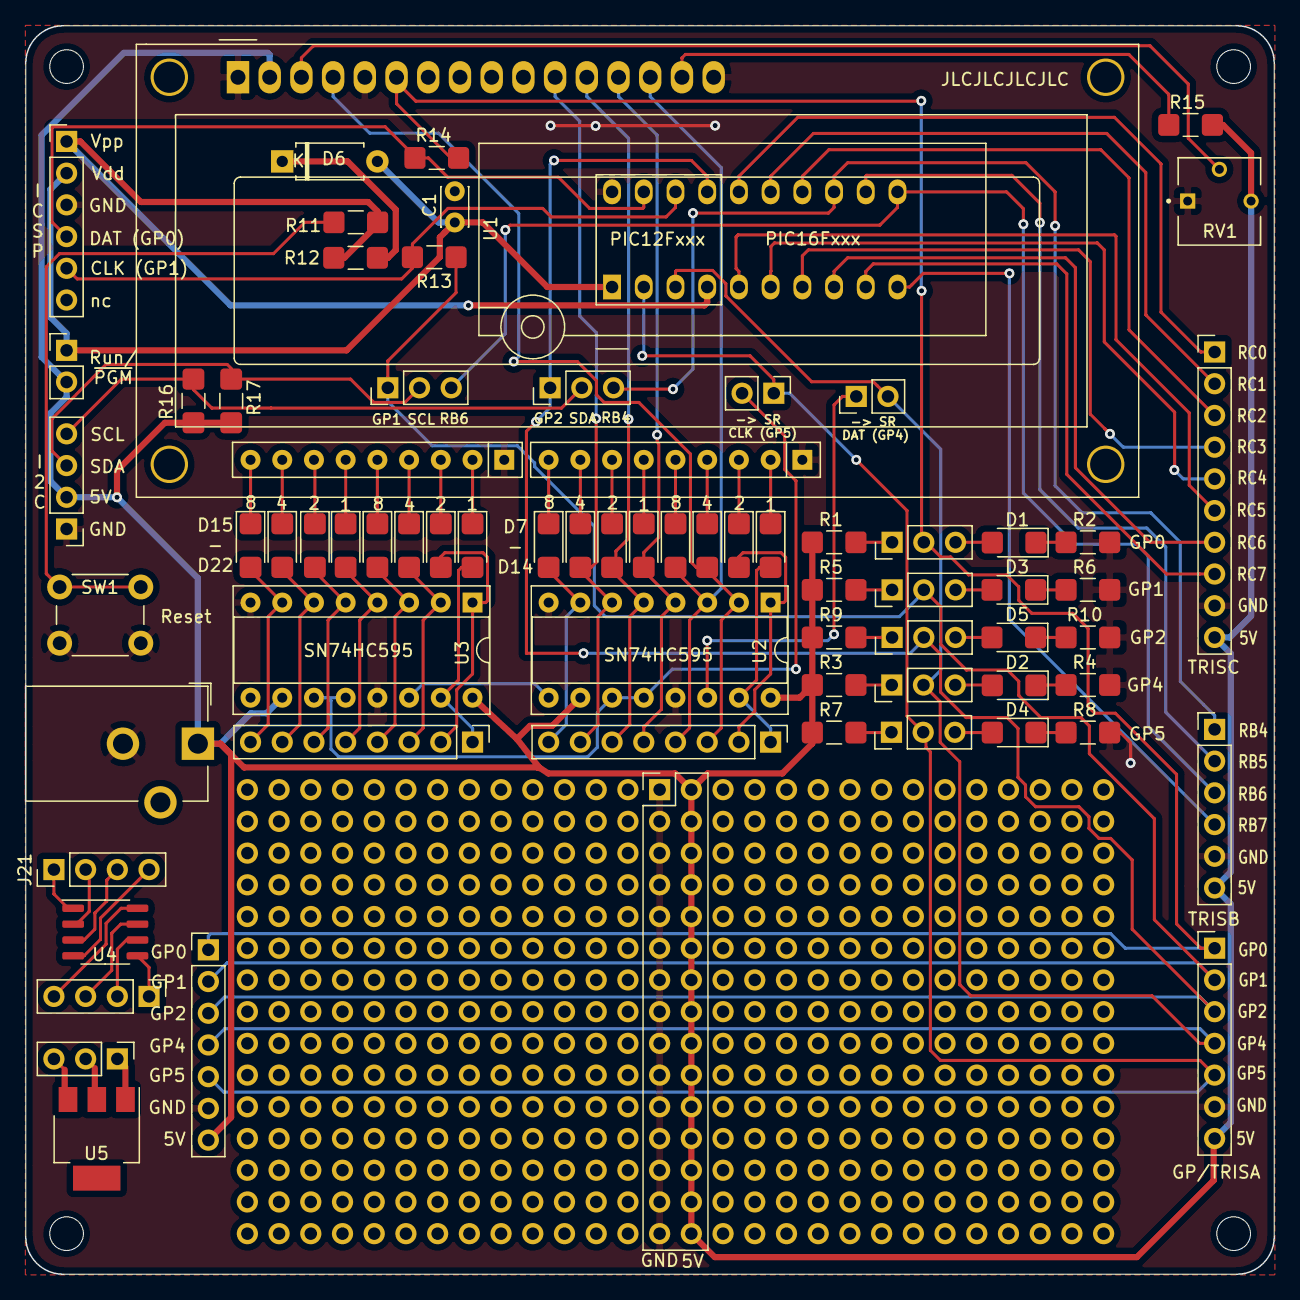
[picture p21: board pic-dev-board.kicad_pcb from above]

Board: 2 copper layers, 100.0 x 100.0 mm, 73 parts (0 on the bottom side), 90 nets.

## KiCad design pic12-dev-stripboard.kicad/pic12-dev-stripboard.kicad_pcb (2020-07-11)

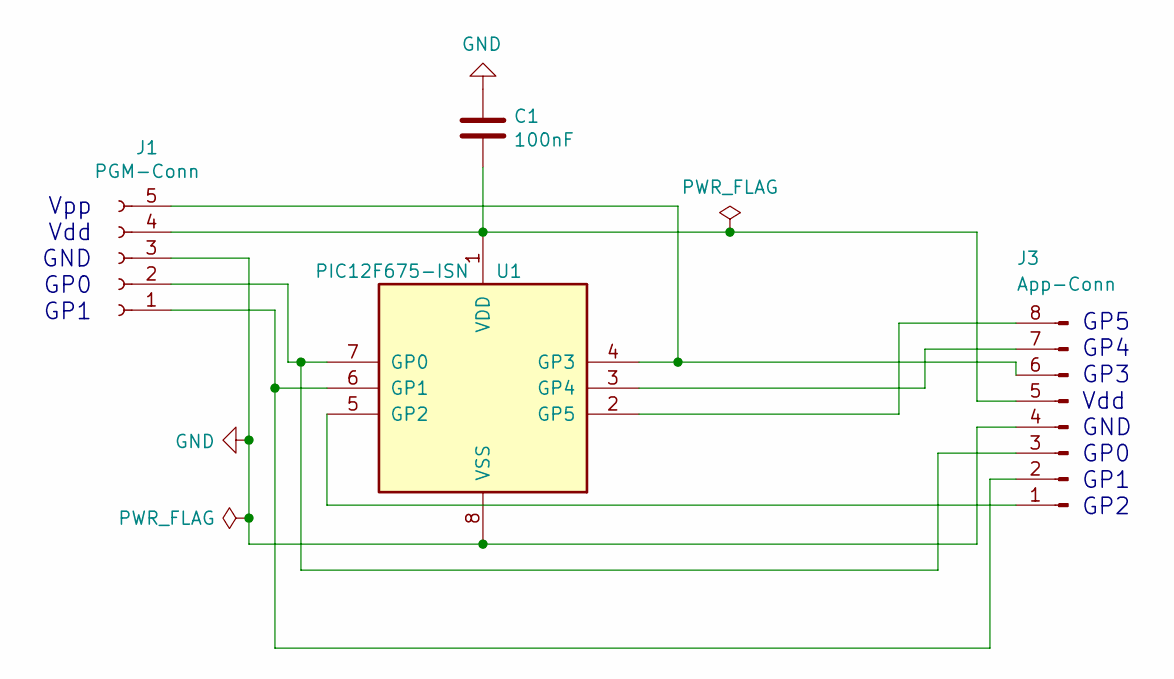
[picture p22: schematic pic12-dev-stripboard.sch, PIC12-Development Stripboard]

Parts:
C1: 100nF; C_Disc_D3.8mm_W2.6mm_P2.50mm
J1: PGM-Conn; PinHeader_1x05_P2.54mm_Vertical
J3: App-Conn; PinHeader_1x08_P2.54mm_Vertical
U1: PIC12F675-ISN; DIP-8_W7.62mm

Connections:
GND: C1.1, J1.3, J3.4, U1.8 (VSS)
unnamed: C1.2, J1.4, J3.5, U1.1 (VDD)
unnamed: J1.1, J3.2, U1.6 (GP1)
unnamed: J1.2, J3.3, U1.7 (GP0)
unnamed: J1.5, J3.6, U1.4 (GP3)
unnamed: J3.1, U1.5 (GP2)
unnamed: J3.7, U1.3 (GP4)
unnamed: J3.8, U1.2 (GP5)

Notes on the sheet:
GP5 GP4 GP3 Vdd GND GP0 GP1 GP2
Vpp Vdd GND GP0 GP1

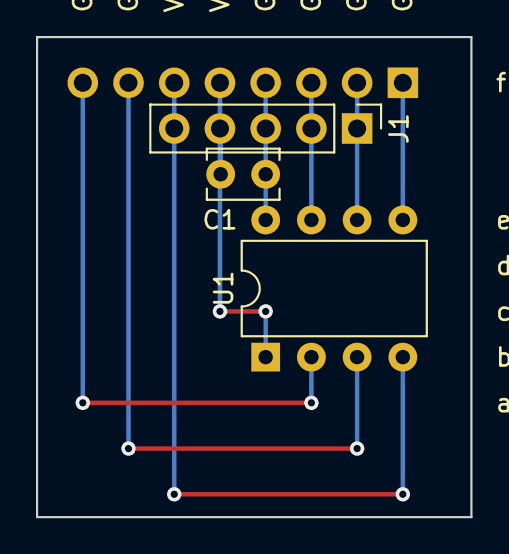
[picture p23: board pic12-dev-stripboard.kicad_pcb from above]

Board: 2 copper layers, 24.1 x 26.7 mm, 4 parts (1 on the bottom side), 8 nets.

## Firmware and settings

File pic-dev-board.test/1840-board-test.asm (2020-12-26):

; 1840-board-test.asm			Steinau, 04.11.2020
; ###########################################################
; Test des 12F1840 auf Bernhards pic-dev-board v. 14.10.20.
; Verwendung interner Osc. / 4 MHz
; 
; Test der LED's der Schiebereg. und RA0-5, außer RA3
; und Ausgabe Bitmuster auf 2x SR595 an RA4,5
;
; Stellung der Jumper auf dem pic-dev-board:
; Run/PGM gesteckt
; Ju GP0,1,2,4,5 jeweils an Pin1-2
; SR: DAT-GP4, CLK-GP5
; I2C: SCL, SDA (Beide Jumper mittig)
;
;
; ###########################################################
;
; Anschlußbelegung:
;
; ICSPDAT,RA0,AN0,		Out LED, alle Pins digital
; ICSPCLK,RA1,AN1,SCL(I2C),	Out LED
;	  RA2,AN2,SDA(I2C),	Out LED
;  /MCLRE,RA3,			Reset
;	  RA4,AN3,		Out LED oder PIN_DATA SR
;	  RA5,			Out LED oder PIN_CLK SR
;	  
; ###########################################################
;	PIC Configuration:

	list		p=12F1840
	#include	<p12f1840.inc>
	movlb	d'0'

; CONFIG PIC12F1840: interner Osc., kein CLKOUT, MCLRE_ON, 
; WDT, PWRT, BOR, CP OFF:

	__CONFIG _CONFIG1, _FOSC_INTOSC & _WDTE_OFF & _PWRTE_OFF & _MCLRE_ON & _CP_OFF & _CPD_OFF & _BOREN_OFF & _CLKOUTEN_OFF
	__CONFIG _CONFIG2, _WRT_OFF & _PLLEN_OFF & _LVP_OFF

; Hexfileformat inhx32 für P12F1840, ok.
; ###########################################################
; EQU's:
	cblock	0x20		; Zeit-UP'e
	miniteil,miditeil,maxiteil,time0,time1,time2,loops,loops2
	endc
;
	cblock	0x30		; SR 595
	srnum,sr8bit,f1,f0
	endc
;
; Verwendung o.g. EQU's:
; srnum : Bitanzahl d. SR595, sr8bit : zu schiebender Wert (SR),
; f1 : High-Wert von 16Bit, f0 : Low-Wert
;
; Definitionen:
;
#define	ledout0	 PORTA,RA0	; LED-OUT für Testzwecke
#define	ledout1	 PORTA,RA1	; LED-OUT für Testzwecke
#define	ledout2	 PORTA,RA2	; LED-OUT für Testzwecke
#define	ledout4	 PORTA,RA4	; LED-OUT für Testzwecke
#define	ledout5	 PORTA,RA5	; LED-OUT für Testzwecke
;
#define PIN_DATA PORTA,RA4	; Signal-Output RA4 (GP4)
#define	PIN_CLK	 PORTA,RA5	; Takt-Output  RA5 (GP5)
;
; ###########################################################
;	org	0x00
	goto	PicInit		; PIC-Initialisierung
;
	org	0x04		; Bank0, für ISR reserviert

; ###########################################################
PicInit
	BANKSEL	PORTA		; Bank0
	clrf	PORTA		; Init PORTA
	clrf	LATA		; PortA u. Latch gelöscht
; alle I/O's Ausgang (TRISA), OSCCON, OSCTUNE (Bank1)
	BANKSEL	TRISA		; Bank1
	clrf	TRISA		; alles Ausgänge

; interner Osc.: OSCCON = 4 MHz (Bank1):
; bit7: SPLLEN=0, bit6-3 IRCF=1101 (4 MHz),
; bit2 U-0, bit1-0=11 Takt vom internen Oscillator Block 
	BANKSEL	OSCCON		; Bank1
	movlw	b'01101011'
	movwf	OSCCON

; Osz.abstimmung factory calibrated TUN<5:0>000000
	BANKSEL	OSCTUNE
	clrf	OSCTUNE

; I/O's digital (ANSELA) (Bank3):
	BANKSEL	ANSELA		; Bank3	
	clrf	ANSELA		; alle Pins digital
;
	movlb	d'0'		; Bank0
;
; ###########################################################
mainx
; 1. Alle PortA-Pins blinken im Sek.-Rythmus:
	movlw	b'00110111'	; alle PortA-Pins=1
	movwf	PORTA
	movlw	d'4'		; 4x250ms = 1s warten
	call	maxitime
;
	movlb	d'0'
	clrf	PORTA	
	movlw	d'4'		; 4x250ms = 1s warten
	call	maxitime
;
; 2. Alle 8 LEDs je SR blinken, wie oben:
	movlw	b'11111111'
	movlb	d'0'
	movwf	f1		; High-Byte SR laden
	movlw	b'11111111'
	movwf	f0		; Low-Byte SR laden
	movf	f1,w		; High-Byte ausgeben
	call	sr595
	movlb	d'0'
	movf	f0,w		; Low-Wert ausgeben
	call	sr595
	call	srtakt1
	movlw	d'4'		; 4x250ms = 1s warten
	call	maxitime
;
	movlb	d'0'
	clrf	f1		; Beide Bytes löschen,
	clrf	f0		; alle LEDs aus
	movf	f1,w		; High-Byte ausgeben
	call	sr595
	movlb	d'0'
	movf	f0,w		; Low-Wert ausgeben
	call	sr595
	call	srtakt1
	movlw	d'4'		; 4x250ms = 1s warten
	call	maxitime
;
	goto	mainx		; Endlosschleife
;
; ###########################################################
; INCLUDE-Dateien:

	#include <quarz_4MHz.asm>	; Warte-UP'e
;	#include <i2c_master_1840.asm>  ; I2C mit MSSP
;	#include <lcdser1bus.asm>	; LCD-Ansteuerungs-UP
;	#include <LCD_Out_1.asm>	; LCD-Ausgaben-UP
	#include <UPsr595.asm>		; Schieberegister-UP

; ###########################################################
; zusätzliche UP'e: 
; ###########################################################

; ############################################################
; UP
; ############################################################


; ###########################################################
	end
; ###########################################################
;
; Programm 1840-board-test.asm

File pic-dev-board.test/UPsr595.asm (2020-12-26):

; #################################################################
; UPsr595.asm					Steinau, 06.06.2020
; #################################################################
; Ausgabe z.B. ADC-Register (16Bit) an 2 SR
;  
; Hier geändertes UP serbits595 zu sr595, Ausgabe 6.6.20, o.k.
;
; Testergebnisse und Beschreibung siehe:
; /home/pi/daten/elektronik/electronic
; /pic-asm-programme/schiebreg595/Texte/sr595.odt
;
; EQU's, z.B.:
;bitnum		equ	0x30
;ser8bit		equ	0x31
;f1		equ	0x32
;f0		equ	0x33
;
; #define's:
;#define	PIN_DATA	GPIO,GP4
;#define	PIN_CLK		GPIO,GP5
;
; Benutzung für 2 Schieberegister z.B. ADC:
;Main
;
;	movf	f1,w		; w=f1=ADRESH
;	call	sr595		; w => SR595
;	movf	f0,w		; w=f0=ADRESL
;	call	sr595		; w => SR595
;	call	srtakt1		; Schlußtakt
;
; Warteschleife zum ablesen der LED-Werte der SR:
;	movlw	d'8'
;	call	maxitime	; 2s warten
;	goto	Main		; neuer Zyklus
;
; #################################################################
; UP sr595: sendet den 8bit-Registerinhalt seriell zum Schiebe- 
; Register und zeigt die Daten an 8 LED's parallel an
; Vor erstem Aufruf muß PIN_CLK=0 sein; z.B. in PicInit: clrf GPIO
; EQU's: bitnum => srnum, ser8bit => sr8bit
; #################################################################
sr595
	movlb	d'0'		; Bank0
	movwf	sr8bit		; sr8bit=w
	movlw	d'8'		; w=8
	movwf	srnum		; srnum=8
nextbit
	bcf	STATUS,C	; C=0
	; zuerst Bit7 ausgeben ?
	rlf	sr8bit,f	; rot. f linksherum durchs Carry
	btfss	STATUS,C	; wenn C=1, überspringe nä. Bef.
	goto	nullout		; C=0, Null senden
einsout				; C=1, Eins senden
	bsf	PIN_DATA	; PIN_DATA=1
;	bcf	PIN_CLK		; Toggeln (low)
	bsf	PIN_CLK		; Toggeln (high)
	bcf	PIN_CLK		; Toggeln (low)
	goto	bitstelle
nullout
	movlb	d'0'		; Bank0
	bcf	PIN_DATA	; PIN_DATA=0
;	bcf	PIN_CLK		; Toggeln (low)
	bsf	PIN_CLK		; Toggeln (high)
	bcf	PIN_CLK		; Toggeln (low)
bitstelle
	decfsz	srnum,f		; srnum-1=0, überspr. nä. Bef.
	goto	nextbit		; srnum > 0, nächste Bitstelle
	return			; srnum = 0, Ende 
				; (UP srtakt1 nicht vergessen)
;
; #################################################################
; UP srtakt1: erzeugt 1 weiteren Takt wegen Verbindung
; SCK u. RCK am SR 74HC595.
; #################################################################
srtakt1
	; Toggeln (9. Takt) wegen der Verbindung SCK und RCK !
	movlb	d'0'		; Bank0
;	bcf	PIN_CLK		; Toggeln (low)
	bsf	PIN_CLK		; Toggeln (high)
	bcf	PIN_CLK		; Takt am Ende auf Low
	return			; alle 8 Bits raus, Fertig!
;
; #################################################################
; ; Ende Datei UPsr595.asm

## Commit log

2020-08-11 moved shift-register to hierarchical sheet / completed connections
    [pic-dev-board.sch]
2020-08-13 added power-connector (barrel-jack)
    [pic-dev-board.sch]
2020-08-13 added jumper to isolate +5V during programming
    [pic-dev-board.sch]
2020-08-13 added I2C-connector
    [pic-dev-board.sch]
2020-08-14 added second shift-register
    [ShiftRegister.sch, pic-dev-board.sch]
2020-08-14 added +5V/GND connectors
    [pic-dev-board.sch]
2020-08-14 added labels, algined parts
    [pic-dev-board.sch]
2020-08-15 added footprints
    [ShiftRegister.sch, pic-dev-board.sch]
2020-08-15 initial commit (outline 10x10cm)
    [pic-dev-board.kicad_pcb]
2020-08-16 changed values of connectors
    [ShiftRegister.sch, pic-dev-board.sch]
2020-08-17 changed +5V/GND connector
    [pic-dev-board.sch]
2020-08-17 added +5V/GND to TRIS_* connectorS
    [pic-dev-board.sch]
2020-08-17 initial pcb-layout, no traces yet
    [pic-dev-board.kicad_pcb]
2020-08-18 added ground-planes
    [pic-dev-board.kicad_pcb]
2020-08-21 finished traces
    [pic-dev-board.kicad_pcb]
2020-08-21 fixed footprint for poti
    [pic-dev-board.kicad_pcb, pic-dev-board.sch]
2020-08-21 updated footprint for +5V/GND connector
    [pic-dev-board.kicad_pcb, pic-dev-board.sch]
2020-08-21 moved reset button and power-connector
    [pic-dev-board.kicad_pcb]
2020-08-21 added second GP/TRISA connector
    [pic-dev-board.kicad_pcb, pic-dev-board.sch]
2020-08-21 added footprint for SO-8
    [pic-dev-board.kicad_pcb]
2020-08-21 added labels
    [pic-dev-board.kicad_pcb]
2020-08-21 Rev1: updated date/revision and added label
    [ShiftRegister.sch, pic-dev-board.kicad_pcb, pic-dev-board.sch]
2020-08-24 bugfixes: no Vdd connection to barrel-jack, missing connection Vpp to R11/R12
    [pic-dev-board.sch]
2020-08-24 I2C-connector: swapped SCL/SDA
    [pic-dev-board.sch]
2020-08-26 removed unnecessary power-flag
    [pic-dev-board.sch]
2020-08-26 reverting Vdd on barrel-jack, power-flag
    [pic-dev-board.sch]
2020-08-26 updated to new I2C-layout
    [pic-dev-board.kicad_pcb]
2020-08-29 updated revision label
    [pic-dev-board.kicad_pcb]
2020-08-29 replaced DIP-socket with textool socket
    [pic-dev-board.sch]
2020-08-31 added SR-connector
    [pic12-dev-pcb.kicad_pcb, pic12-dev-pcb.sch]
2020-09-04 layout with textool
    [pic-dev-board.kicad_pcb]
2020-09-07 fine-tuning of traces
    [pic-dev-board.kicad_pcb]
2020-09-07 Rev4: added SO-8/SOT-223 components to schema to prevent DRC-errors on pcb
    [pic-dev-board.kicad_pcb, pic-dev-board.sch]
2020-09-07 Rev 2: different layout, SR connector
    [pic12-dev-pcb.kicad_pcb, pic12-dev-pcb.sch]
2020-09-10 fine-tuning of labels
    [pic-dev-board.kicad_pcb]
2020-09-17 place SR-connector, add markers
    [pic12-dev-pcb.kicad_pcb]
2020-09-17 fix labeling of GP2 net, add USB-connector
    [pic12-dev-pcb.sch]
2020-09-19 swap GP0-GP2, add micro-USB breakout
    [pic12-dev-pcb.kicad_pcb, pic12-dev-pcb.sch]
2020-09-22 updated gerber-export options
    [pic-dev-board.kicad_pcb]
2020-09-22 added JLC-number field
    [pic-dev-board.kicad_pcb]
2020-09-25 changed SO-8 footprint to handsolder-version
    [pic12-dev-pcb.sch]
2020-09-25 updated footprints, added prototyping area
    [pic12-dev-pcb.kicad_pcb]
2020-09-29 move SR-connector to edge
    [pic12-dev-pcb.kicad_pcb]
2020-09-29 optimized labels
    [pic12-dev-pcb.kicad_pcb]
2020-10-07 updated netlist for pic-dev-board
2020-10-09 minor changes
    [pic-dev-board-BOM.ods]
2020-10-09 added description of pcbs
2020-10-12 added formatting
    [pic-dev-board-BOM.ods]
2020-10-13 bugfix: labels for GP4/GP5 had CLK/DAT swapped
    [pic-dev-board.kicad_pcb]
2020-10-23 added link to image of dev-board
2020-10-28 Rev4: fixed order of pins of SR-connector
    [pic12-dev-pcb.kicad_pcb, pic12-dev-pcb.sch]
2020-10-30 Rev5: added GP3 to connectors
    [pic12-dev-pcb.kicad_pcb, pic12-dev-pcb.sch]
2020-10-30 Rev6: added LEDs and button
    [pic12-dev-pcb.kicad_pcb, pic12-dev-pcb.sch]
2020-11-06 changed filenames to have a consistent scheme
    [pic-dev-board-base.stl]
2021-03-12 updated to current version
2021-03-12 updated specs of pic12-dev-pcb
2021-04-21 pic20-dev-pcb: Rev 1.2: use DIP-20 footprint for PIC
    [pic20-dev-pcb.kicad_pcb, pic20-dev-pcb.sch]
2021-04-21 pic20-dev-pcb: Rev 1.3: add SPI-connector, use socket for PIC
    [pic20-dev-pcb.kicad_pcb, pic20-dev-pcb.sch]
2021-04-22 updated footprint for micro-usb
    [pic20-dev-pcb.kicad_pcb, pic20-dev-pcb.sch]
2021-04-26 optimized layout
    [pic20-dev-pcb.kicad_pcb]
2021-04-29 pic20-dev-pcb: Rev 1.4: optimizations, prep for production
    [pic20-dev-pcb.kicad_pcb, pic20-dev-pcb.sch]
2021-05-21 Rev 1.5: bugfix Micro-USB connector
    [pic20-dev-pcb.kicad_pcb, pic20-dev-pcb.sch]
